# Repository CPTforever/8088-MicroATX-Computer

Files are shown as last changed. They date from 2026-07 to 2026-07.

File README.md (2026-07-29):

# Insert header here

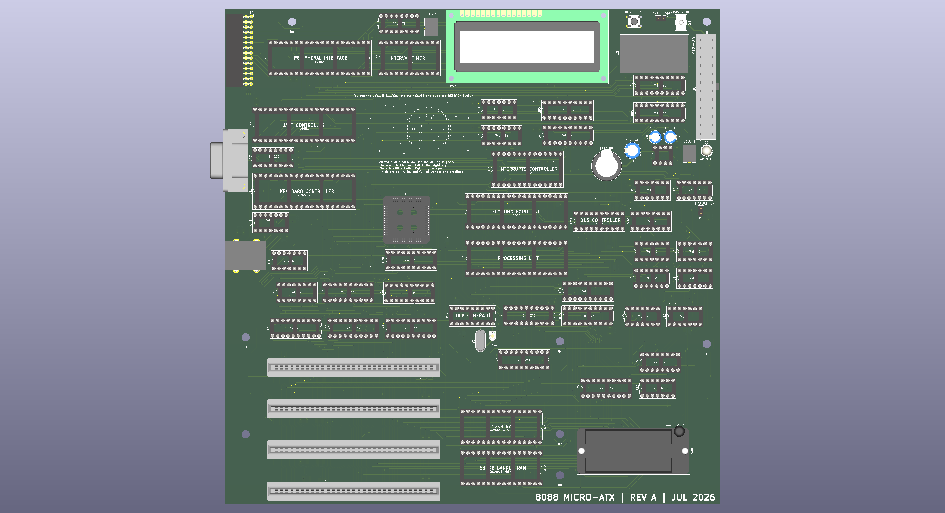
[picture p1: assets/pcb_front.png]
pcb_front

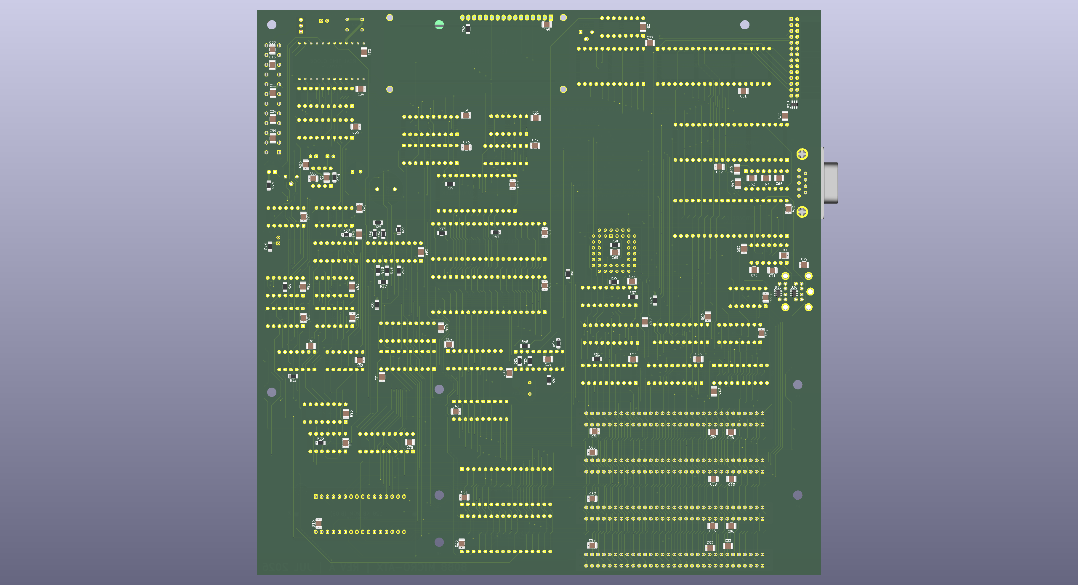
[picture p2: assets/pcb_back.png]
pcb_back

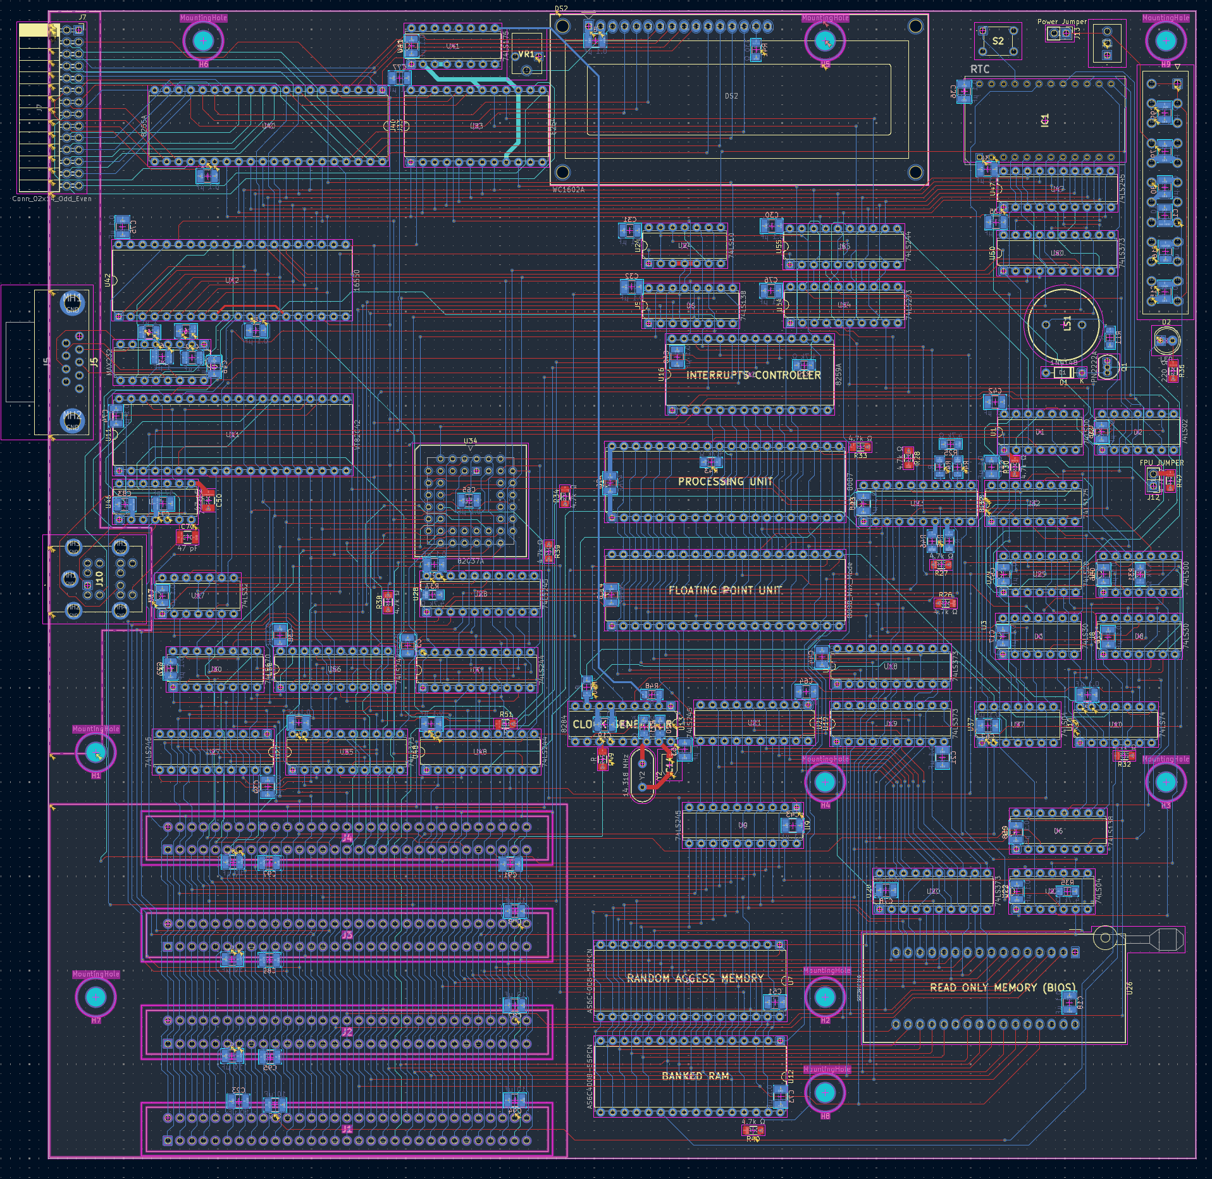
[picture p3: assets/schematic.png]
schematic

# Features!
insert features

# Memory Map
Insert memory map

# I/O Port Map
Insert port map

# Rev 1 Mistakes
UART Controller uses system clock instead of external crystal, meaning standard baud rates are
only achievable when system clock uses a UART compatible crystal

PIT Gate 1 does not have a pull up resistor, meaning gate is floating when the external io pin is not connected. (This can be bodged with a radial resistor at least.)

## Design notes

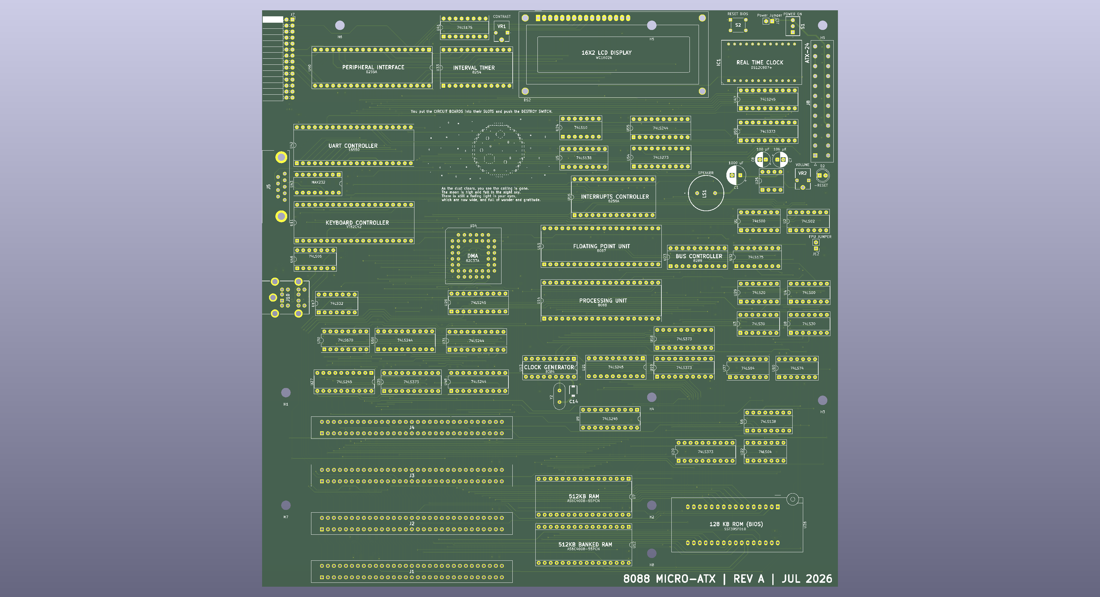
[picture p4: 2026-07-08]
assets/pcb_front_bare.png

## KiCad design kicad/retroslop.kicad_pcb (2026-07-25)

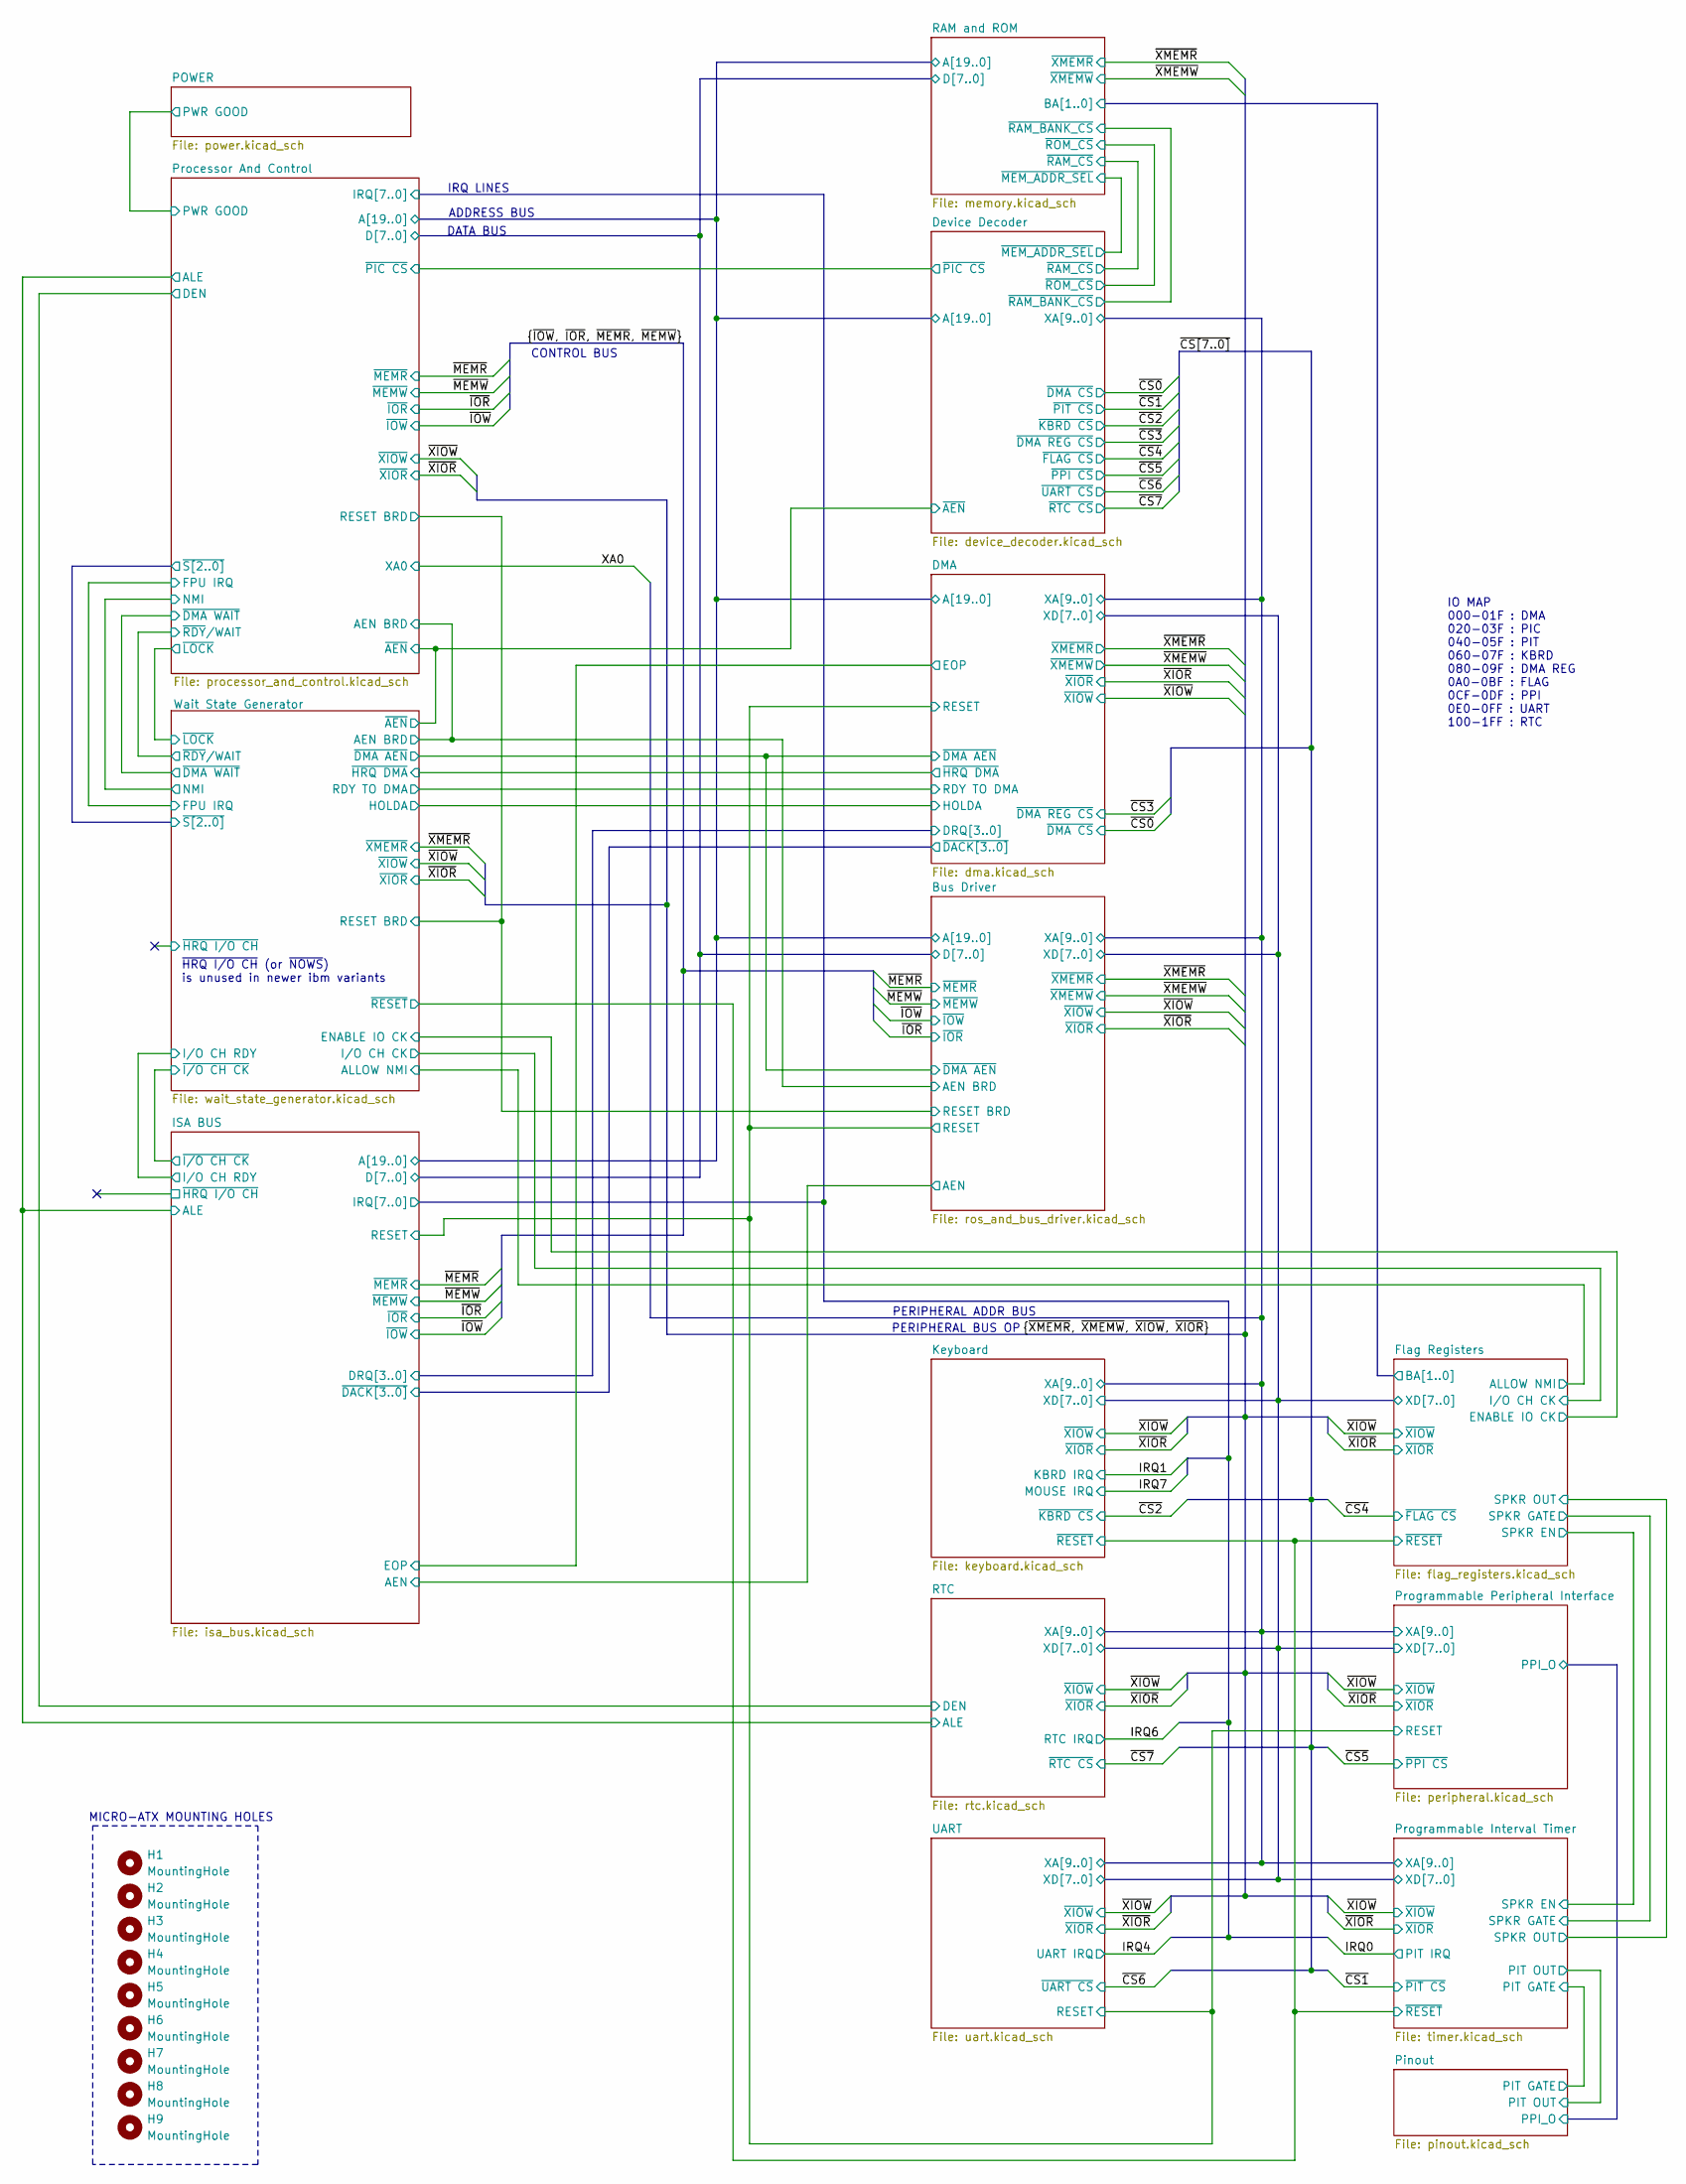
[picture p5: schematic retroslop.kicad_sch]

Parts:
H1, H2, H3, H4, H5, H6, H7, H8, H9: MountingHole; MountingHole_4mm

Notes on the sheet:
DATA BUS
IRQ LINES
IO MAP 000-01F : DMA 020-03F : PIC 040-05F : PIT 060-07F : KBRD 080-09F : DMA REG 0A0-0BF : FLAG 0CF-0DF : PPI 0E0-0FF : UART 100-1FF : RTC
~{HRQ I/O CH} (or ~{NOWS}) is unused in newer ibm variants
ADDRESS BUS
MICRO-ATX MOUNTING HOLES
PERIPHERAL ADDR BUS
CONTROL BUS
PERIPHERAL BUS OP

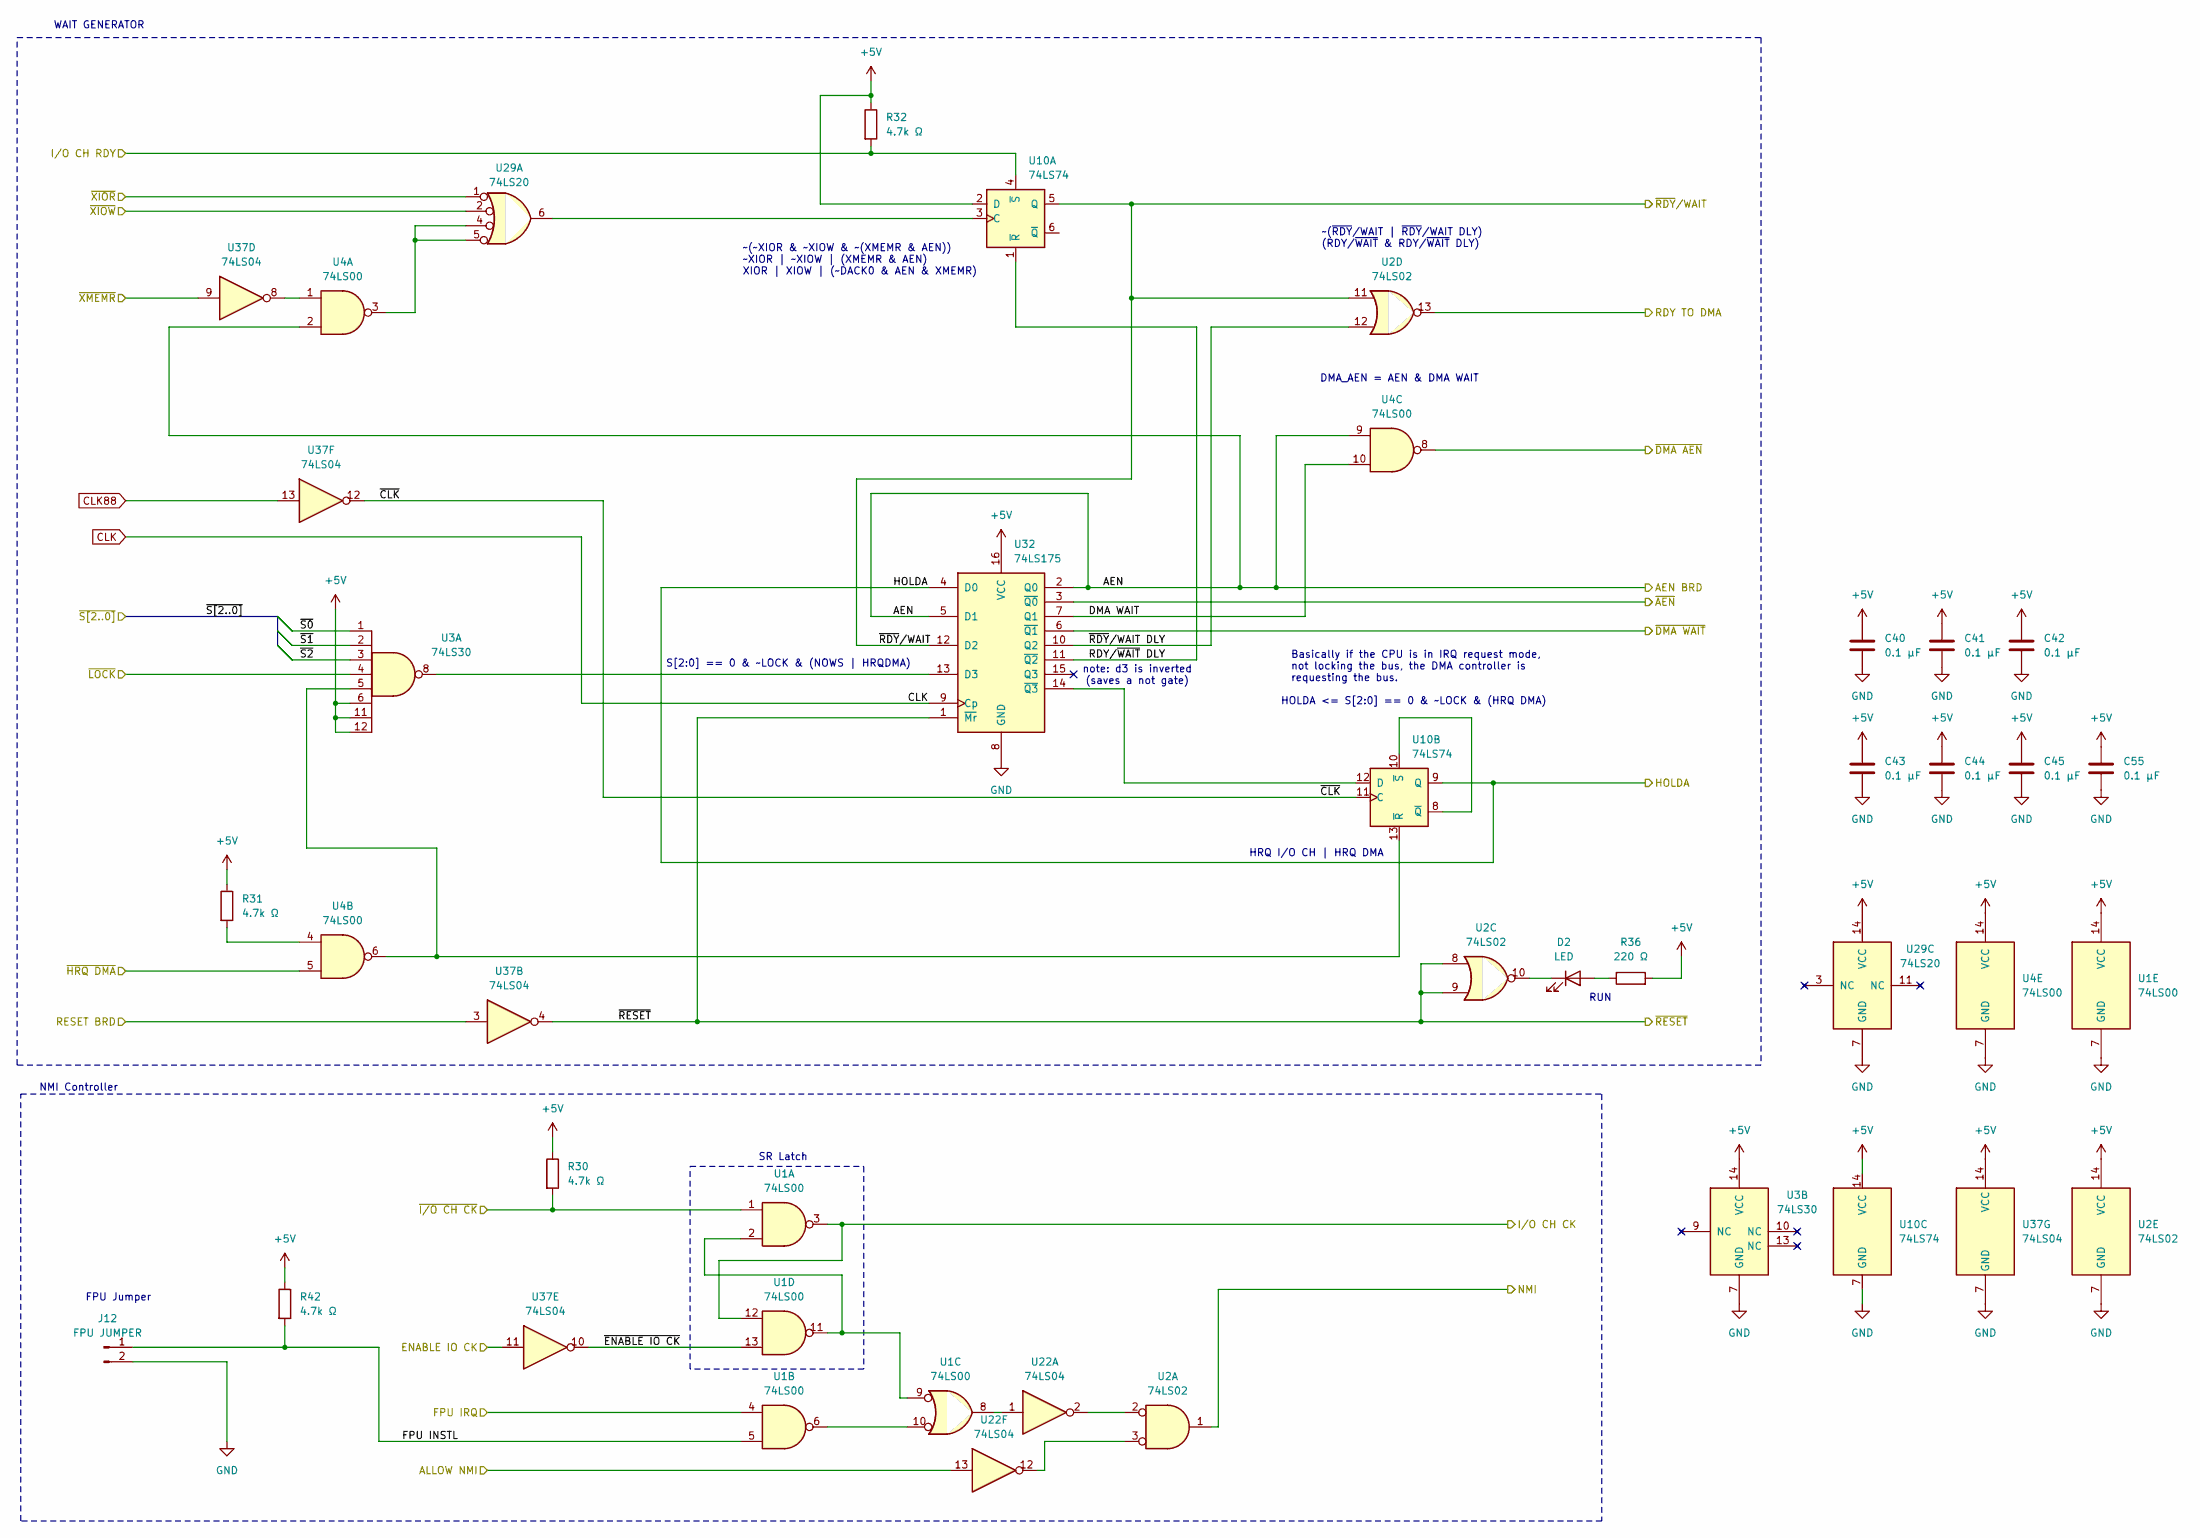
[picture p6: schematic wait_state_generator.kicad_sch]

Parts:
C40, C41, C42, C43, C44, C45, C55: 0.1 μF; C_1210_3225Metric_Pad1.33x2.70mm_HandSolder
D2: LED; LED_D5.0mm_Clear
J12: FPU JUMPER; PinHeader_1x02_P2.54mm_Vertical
R30, R31, R32, R42: 4.7k Ω; R_1206_3216Metric_Pad1.30x1.75mm_HandSolder
R36: 220 Ω; R_1206_3216Metric_Pad1.30x1.75mm_HandSolder
U1, U4: 74LS00; DIP-14_W7.62mm_Socket
U2: 74LS02; DIP-14_W7.62mm_Socket
U3: 74LS30; DIP-14_W7.62mm_Socket
U10: 74LS74; DIP-14_W7.62mm_Socket
U22, U37: 74LS04; DIP-14_W7.62mm_Socket
U29: 74LS20; DIP-14_W7.62mm_Socket
U32: 74LS175; DIP-16_W7.62mm_Socket

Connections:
+5V: C40.1, C41.1, C42.1, C43.1, C44.1, C45.1, C55.1, R30.1, R31.1, R32.1, R36.2, R42.1, U1.14 (VCC), U2.14 (VCC), U3.6, U3.11, U3.12, U3.14 (VCC), U4.14 (VCC), U10.2 (D), U10.14 (VCC), U29.14 (VCC), U32.16 (VCC), U37.14 (VCC); also elsewhere on the board
/Bus Driver/RESET BRD: U37.3; also elsewhere on the board
/Bus Driver/~DMA AEN: U4.8; also elsewhere on the board
/DMA/RDY TO DMA: U2.13; also elsewhere on the board
/DMA/~HRQ DMA: U4.5; also elsewhere on the board
/Device Decoder/~AEN: U32.3 (~Q0); also elsewhere on the board
/Flag Registers/ALLOW NMI: U22.13; also elsewhere on the board
/Flag Registers/ENABLE IO CK: U37.11; also elsewhere on the board
/Flag Registers/I/O CH CK: U1.3, U1.12; also elsewhere on the board
/ISA BUS/I/O CH RDY: R32.2, U10.4 (~S); also elsewhere on the board
/ISA BUS/~I/O CH CK: R30.2, U1.1; also elsewhere on the board
/Processor And Control/FPU IRQ: U1.4; also elsewhere on the board
/Processor And Control/NMI: U2.1; also elsewhere on the board
/Processor And Control/~DMA WAIT: U32.6 (~Q1); also elsewhere on the board
/Processor And Control/~LOCK: U3.4; also elsewhere on the board
/Processor And Control/~S0: U3.1; also elsewhere on the board
/Processor And Control/~S1: U3.2; also elsewhere on the board
/Processor And Control/~S2: U3.3; also elsewhere on the board
/Wait State Generator/AEN: U4.2, U4.9, U32.2 (Q0), U32.5 (D1); also elsewhere on the board
/Wait State Generator/DMA WAIT: U4.10, U32.7 (Q1)
/Wait State Generator/FPU INSTL: J12.1, R42.2, U1.5
/Wait State Generator/HOLDA: U10.9 (Q), U32.4 (D0); also elsewhere on the board
/Wait State Generator/RDY/~WAIT DLY: U10.1 (~R), U32.11 (~Q2)
/Wait State Generator/~CLK: U10.11 (C), U37.12
/Wait State Generator/~ENABLE IO CK: U1.13, U37.10
/Wait State Generator/~RDY/WAIT: U2.11, U10.5 (Q), U32.12 (D2); also elsewhere on the board
/Wait State Generator/~RDY/WAIT DLY: U2.12, U32.10 (Q2)
/Wait State Generator/~RESET: U2.8, U2.9, U32.1 (~Mr), U37.4; also elsewhere on the board
/~XIOR: U29.1; also elsewhere on the board
/~XIOW: U29.2; also elsewhere on the board
/~XMEMR: U37.9; also elsewhere on the board
CLK: U32.9 (Cp); also elsewhere on the board
CLK88: U37.13; also elsewhere on the board
GND: C40.2, C41.2, C42.2, C43.2, C44.2, C45.2, C55.2, J12.2, U1.7 (GND), U2.7 (GND), U3.7 (GND), U4.7 (GND), U10.7 (GND), U29.7 (GND), U32.8 (GND), U37.7 (GND); also elsewhere on the board
unnamed: D2.2 (A), R36.1
unnamed: D2.1 (K), U2.10
unnamed: R31.2, U4.4
unnamed: U1.8, U22.1
unnamed: U1.6, U1.10
unnamed: U1.2, U1.9, U1.11
unnamed: U2.2, U22.2
unnamed: U2.3, U22.12
unnamed: U10.3 (C), U29.6
unnamed: U10.12 (D), U32.14 (~Q3)
unnamed: U10.8 (~Q), U10.10 (~S)
unnamed: U3.5, U4.6, U10.13 (~R)
unnamed: U4.3, U29.4, U29.5
unnamed: U3.8, U32.13 (D3)
unnamed: U4.1, U37.8

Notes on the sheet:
note: d3 is inverted (saves a not gate)
NMI Controller
RUN
~(~XIOR & ~XIOW & ~(XMEMR & AEN)) ~XIOR | ~XIOW | (XMEMR & AEN) XIOR | XIOW | (~DACK0 & AEN & XMEMR)
WAIT GENERATOR
SR Latch
Basically if the CPU is in IRQ request mode, not locking the bus, the DMA controller is requesting the bus.
HRQ I/O CH | HRQ DMA
FPU Jumper
HOLDA <= S[2:0] == 0 & ~LOCK & (HRQ DMA)
S[2:0] == 0 & ~LOCK & (NOWS | HRQDMA)
DMA_AEN = AEN & DMA WAIT
~(~{RDY}/WAIT | ~{RDY}/WAIT DLY) (RDY/~{WAIT} & RDY/~{WAIT} DLY)

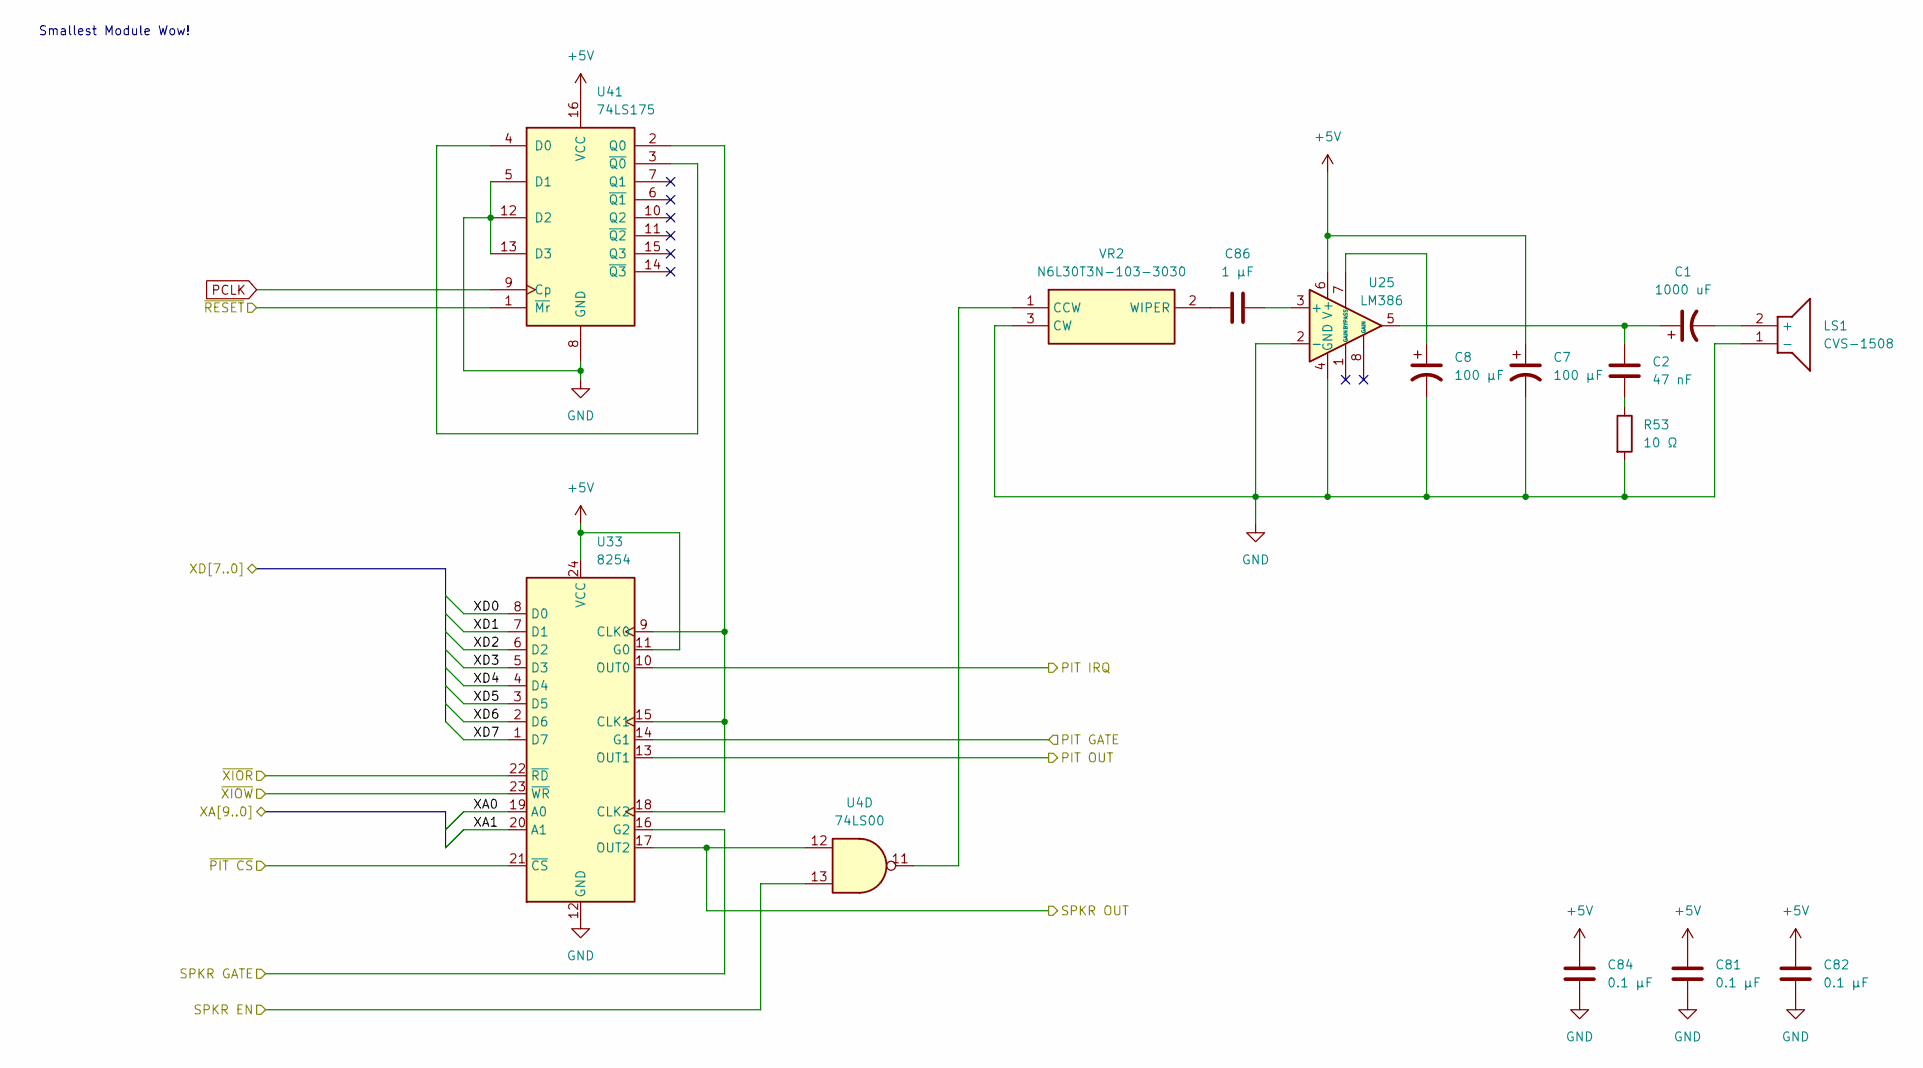
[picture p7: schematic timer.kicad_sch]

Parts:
C1: 1000 uF; CP_Radial_D8.0mm_P3.50mm
C2: 47 nF; C_1210_3225Metric_Pad1.33x2.70mm_HandSolder
C7, C8: 100 μF; CP_Radial_D6.3mm_P2.50mm
C81, C82, C84: 0.1 μF; C_1210_3225Metric_Pad1.33x2.70mm_HandSolder
C86: 1 μF; C_1210_3225Metric_Pad1.33x2.70mm_HandSolder
LS1: CVS-1508; Mouser Part Number 490-CVS-1508
R53: 10 Ω; R_1206_3216Metric_Pad1.30x1.75mm_HandSolder
U4: 74LS00; DIP-14_W7.62mm_Socket
U25: LM386; DIP-8_W7.62mm_Socket
U33: 8254; DIP-24_W15.24mm_Socket
U41: 74LS175; DIP-16_W7.62mm_Socket
VR2: N6L30T3N-103-3030; N6L30T3N1033030; Manufacturer_Part_Number N6L30T3N-103-3030

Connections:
+5V: C7.1, C81.1, C82.1, C84.1, U25.6 (V+), U33.11 (G0), U33.24 (VCC), U41.16 (VCC); also elsewhere on the board
/Bus Driver/XA0: U33.19 (A0); also elsewhere on the board
/Bus Driver/XA1: U33.20 (A1); also elsewhere on the board
/Bus Driver/XD0: U33.8 (D0); also elsewhere on the board
/Bus Driver/XD1: U33.7 (D1); also elsewhere on the board
/Bus Driver/XD2: U33.6 (D2); also elsewhere on the board
/Bus Driver/XD3: U33.5 (D3); also elsewhere on the board
/Bus Driver/XD4: U33.4 (D4); also elsewhere on the board
/Bus Driver/XD5: U33.3 (D5); also elsewhere on the board
/Bus Driver/XD6: U33.2 (D6); also elsewhere on the board
/Bus Driver/XD7: U33.1 (D7); also elsewhere on the board
/Flag Registers/SPKR EN: U4.13; also elsewhere on the board
/Flag Registers/SPKR GATE: U33.16 (G2); also elsewhere on the board
/Flag Registers/SPKR OUT: U4.12, U33.17 (OUT2); also elsewhere on the board
/Pinout/PIT GATE: U33.14 (G1); also elsewhere on the board
/Pinout/PIT OUT: U33.13 (OUT1); also elsewhere on the board
/Processor And Control/IRQ0: U33.10 (OUT0); also elsewhere on the board
/Wait State Generator/~RESET: U41.1 (~Mr); also elsewhere on the board
/~CS1: U33.21 (~CS); also elsewhere on the board
/~XIOR: U33.22 (~RD); also elsewhere on the board
/~XIOW: U33.23 (~WR); also elsewhere on the board
GND: C7.2, C8.2, C81.2, C82.2, C84.2, LS1.1 (-), R53.2, U25.2 (-), U25.4 (GND), U33.12 (GND), U41.5 (D1), U41.8 (GND), U41.12 (D2), U41.13 (D3), VR2.3 (CW); also elsewhere on the board
unnamed: C1.1, C2.1, U25.5
unnamed: C2.2, R53.1
unnamed: C1.2, LS1.2 (+)
unnamed: C86.2, U25.3 (+)
unnamed: C8.1, U25.7 (BYPASS)
unnamed: U33.9 (CLK0), U33.15 (CLK1), U33.18 (CLK2), U41.2 (Q0)
unnamed: U41.3 (~Q0), U41.4 (D0)
unnamed: U4.11, VR2.1 (CCW)
unnamed: C86.1, VR2.2 (WIPER)
PCLK: U41.9 (Cp); also elsewhere on the board

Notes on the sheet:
Smallest Module Wow!

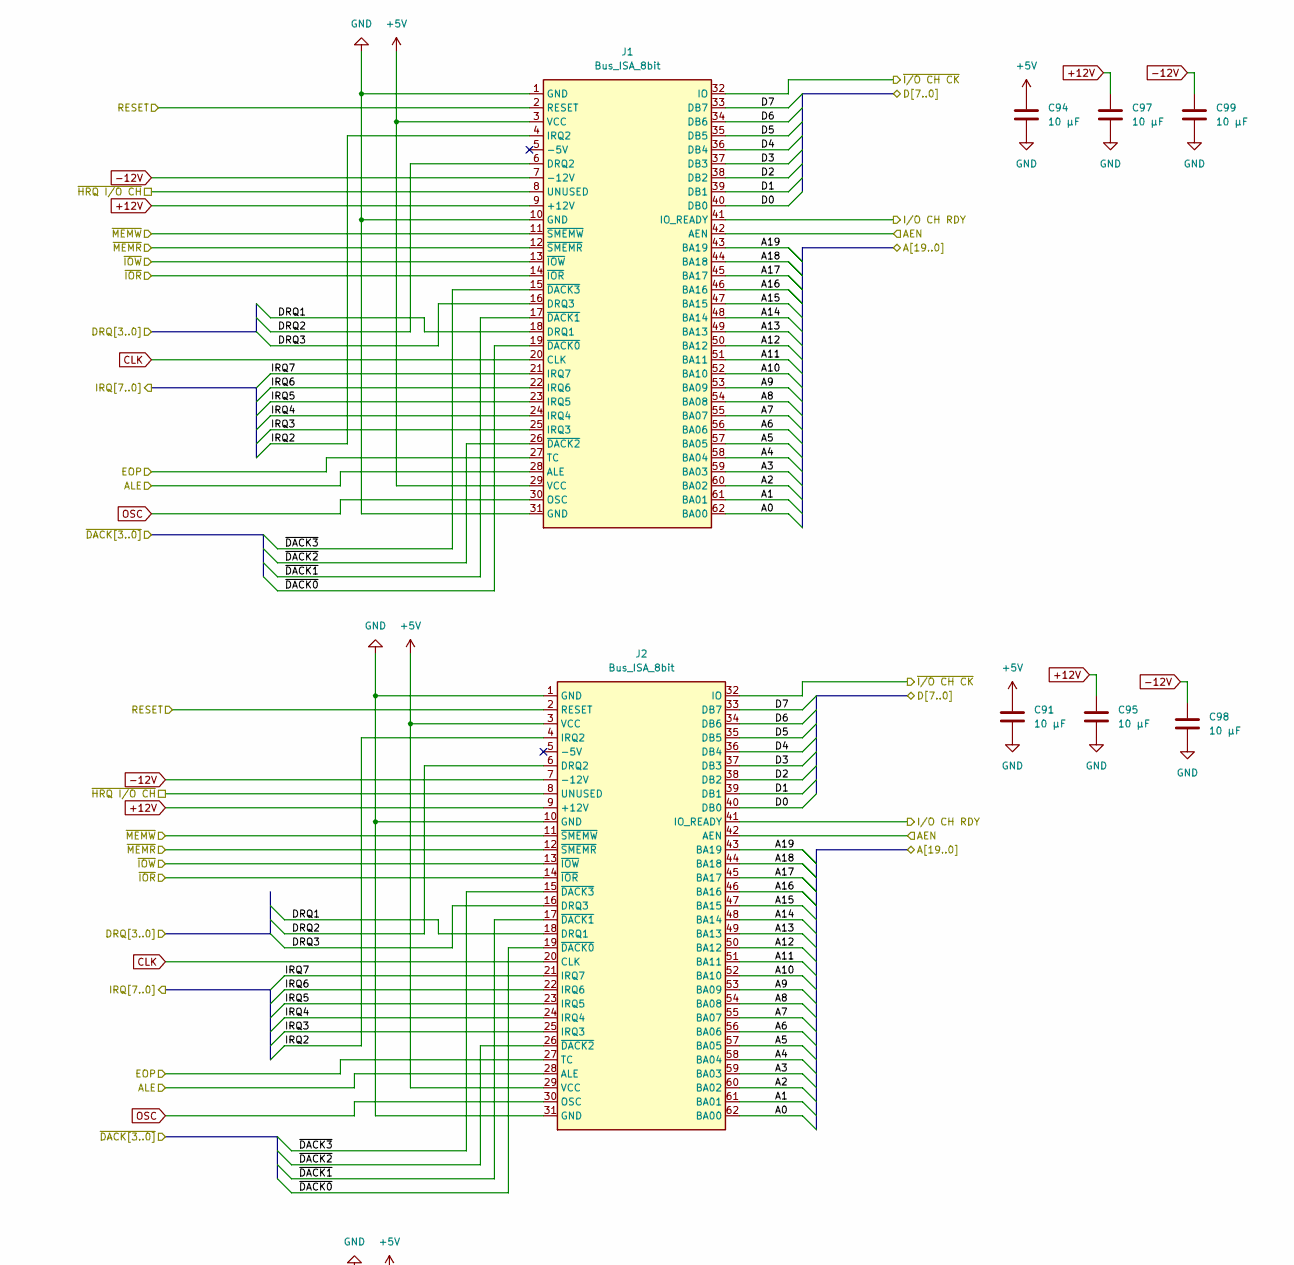
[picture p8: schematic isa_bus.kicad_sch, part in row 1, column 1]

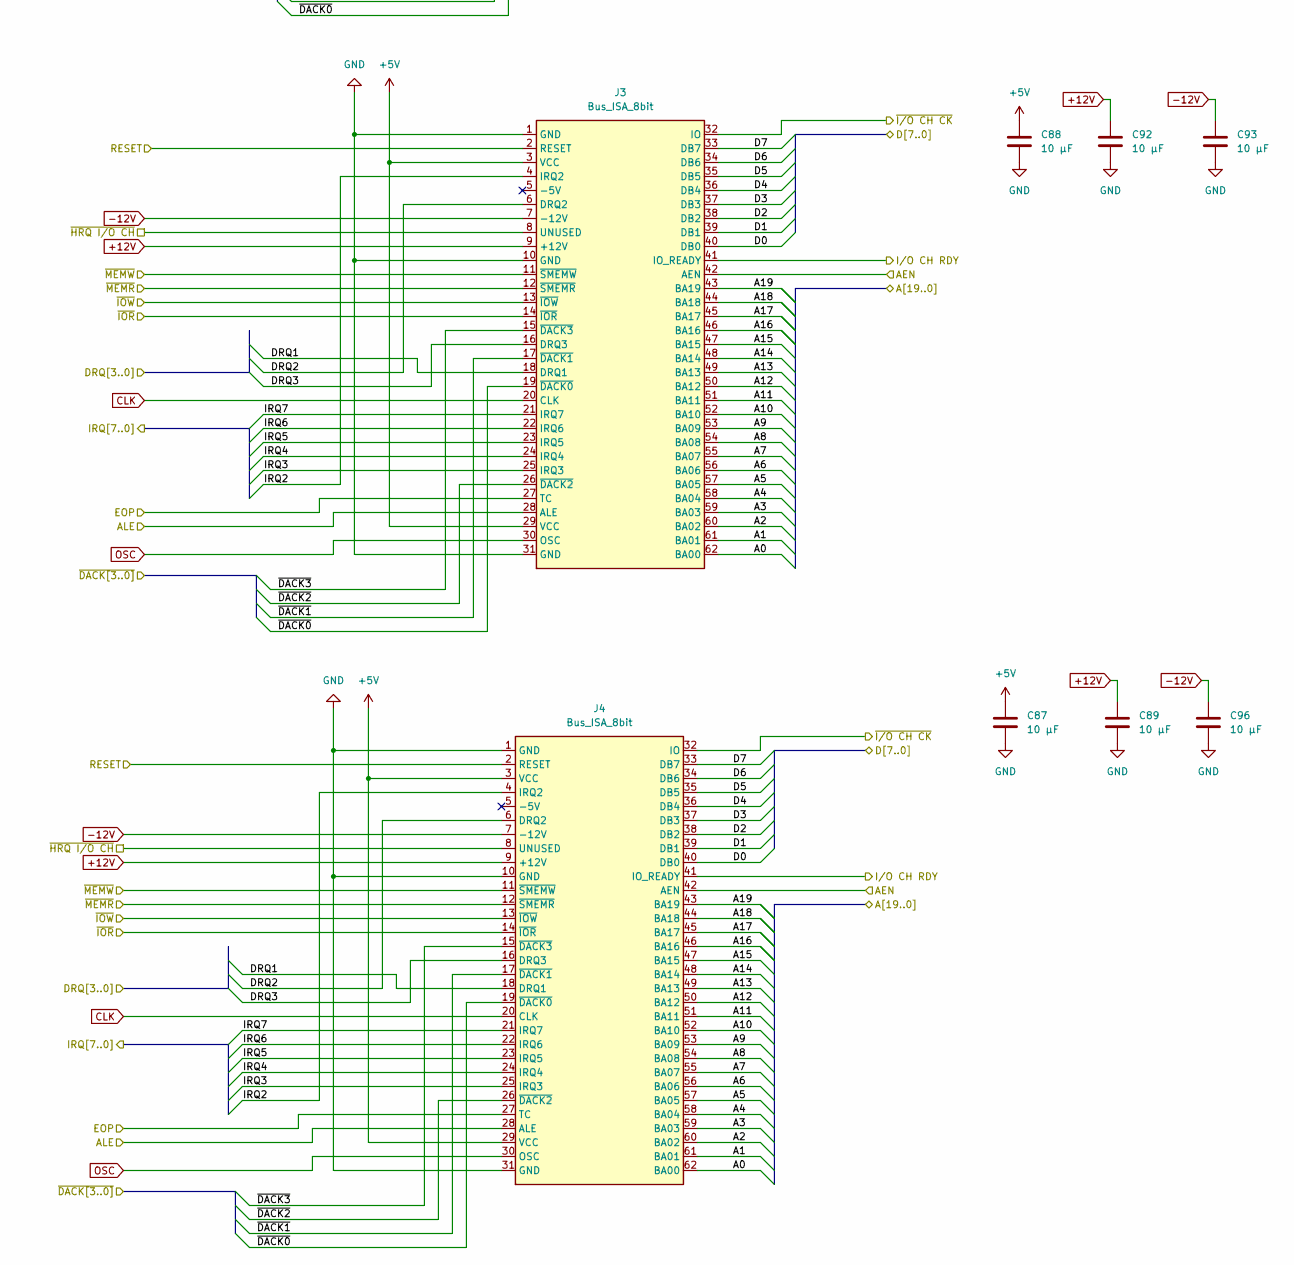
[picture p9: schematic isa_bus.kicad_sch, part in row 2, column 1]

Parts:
C87, C88, C89, C91, C92, C93, C94, C95, C96, C97, C98, C99: 10 μF; C_1210_3225Metric_Pad1.33x2.70mm_HandSolder
J1, J2, J3, J4: Bus_ISA_8bit; 655308435

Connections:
+5V: C87.1, C88.1, C91.1, C94.1, J1.3 (VCC), J1.29 (VCC), J2.3 (VCC), J2.29 (VCC), J3.3 (VCC), J3.29 (VCC), J4.3 (VCC), J4.29 (VCC); also elsewhere on the board
+12V: C89.1, C92.1, C95.1, C97.1, J1.9 (+12V), J2.9 (+12V), J3.9 (+12V), J4.9 (+12V); also elsewhere on the board
-12V: C93.1, C96.1, C98.1, C99.1, J1.7 (-12V), J2.7 (-12V), J3.7 (-12V), J4.7 (-12V); also elsewhere on the board
/Bus Driver/A0: J1.62 (BA00), J2.62 (BA00), J3.62 (BA00), J4.62 (BA00); also elsewhere on the board
/Bus Driver/A1: J1.61 (BA01), J2.61 (BA01), J3.61 (BA01), J4.61 (BA01); also elsewhere on the board
/Bus Driver/A2: J1.60 (BA02), J2.60 (BA02), J3.60 (BA02), J4.60 (BA02); also elsewhere on the board
/Bus Driver/A3: J1.59 (BA03), J2.59 (BA03), J3.59 (BA03), J4.59 (BA03); also elsewhere on the board
/Bus Driver/A4: J1.58 (BA04), J2.58 (BA04), J3.58 (BA04), J4.58 (BA04); also elsewhere on the board
/Bus Driver/A5: J1.57 (BA05), J2.57 (BA05), J3.57 (BA05), J4.57 (BA05); also elsewhere on the board
/Bus Driver/A6: J1.56 (BA06), J2.56 (BA06), J3.56 (BA06), J4.56 (BA06); also elsewhere on the board
/Bus Driver/A7: J1.55 (BA07), J2.55 (BA07), J3.55 (BA07), J4.55 (BA07); also elsewhere on the board
/Bus Driver/A8: J1.54 (BA08), J2.54 (BA08), J3.54 (BA08), J4.54 (BA08); also elsewhere on the board
/Bus Driver/A9: J1.53 (BA09), J2.53 (BA09), J3.53 (BA09), J4.53 (BA09); also elsewhere on the board
/Bus Driver/A10: J1.52 (BA10), J2.52 (BA10), J3.52 (BA10), J4.52 (BA10); also elsewhere on the board
/Bus Driver/A11: J1.51 (BA11), J2.51 (BA11), J3.51 (BA11), J4.51 (BA11); also elsewhere on the board
/Bus Driver/A12: J1.50 (BA12), J2.50 (BA12), J3.50 (BA12), J4.50 (BA12); also elsewhere on the board
/Bus Driver/A13: J1.49 (BA13), J2.49 (BA13), J3.49 (BA13), J4.49 (BA13); also elsewhere on the board
/Bus Driver/A14: J1.48 (BA14), J2.48 (BA14), J3.48 (BA14), J4.48 (BA14); also elsewhere on the board
/Bus Driver/A15: J1.47 (BA15), J2.47 (BA15), J3.47 (BA15), J4.47 (BA15); also elsewhere on the board
/Bus Driver/A16: J1.46 (BA16), J2.46 (BA16), J3.46 (BA16), J4.46 (BA16); also elsewhere on the board
/Bus Driver/A17: J1.45 (BA17), J2.45 (BA17), J3.45 (BA17), J4.45 (BA17); also elsewhere on the board
/Bus Driver/A18: J1.44 (BA18), J2.44 (BA18), J3.44 (BA18), J4.44 (BA18); also elsewhere on the board
/Bus Driver/A19: J1.43 (BA19), J2.43 (BA19), J3.43 (BA19), J4.43 (BA19); also elsewhere on the board
/Bus Driver/AEN: J1.42 (AEN), J2.42 (AEN), J3.42 (AEN), J4.42 (AEN); also elsewhere on the board
/Bus Driver/D0: J1.40 (DB0), J2.40 (DB0), J3.40 (DB0), J4.40 (DB0); also elsewhere on the board
/Bus Driver/D1: J1.39 (DB1), J2.39 (DB1), J3.39 (DB1), J4.39 (DB1); also elsewhere on the board
/Bus Driver/D2: J1.38 (DB2), J2.38 (DB2), J3.38 (DB2), J4.38 (DB2); also elsewhere on the board
/Bus Driver/D3: J1.37 (DB3), J2.37 (DB3), J3.37 (DB3), J4.37 (DB3); also elsewhere on the board
/Bus Driver/D4: J1.36 (DB4), J2.36 (DB4), J3.36 (DB4), J4.36 (DB4); also elsewhere on the board
/Bus Driver/D5: J1.35 (DB5), J2.35 (DB5), J3.35 (DB5), J4.35 (DB5); also elsewhere on the board
/Bus Driver/D6: J1.34 (DB6), J2.34 (DB6), J3.34 (DB6), J4.34 (DB6); also elsewhere on the board
/Bus Driver/D7: J1.33 (DB7), J2.33 (DB7), J3.33 (DB7), J4.33 (DB7); also elsewhere on the board
/Bus Driver/RESET: J1.2 (RESET), J2.2 (RESET), J3.2 (RESET), J4.2 (RESET); also elsewhere on the board
/DMA/DRQ1: J1.18 (DRQ1), J2.18 (DRQ1), J3.18 (DRQ1), J4.18 (DRQ1); also elsewhere on the board
/DMA/DRQ2: J1.6 (DRQ2), J2.6 (DRQ2), J3.6 (DRQ2), J4.6 (DRQ2); also elsewhere on the board
/DMA/DRQ3: J1.16 (DRQ3), J2.16 (DRQ3), J3.16 (DRQ3), J4.16 (DRQ3); also elsewhere on the board
/DMA/Terminal Count: J1.27 (TC), J2.27 (TC), J3.27 (TC), J4.27 (TC); also elsewhere on the board
/DMA/~DACK0: J1.19 (~DACK0), J2.19 (~DACK0), J3.19 (~DACK0), J4.19 (~DACK0); also elsewhere on the board
/DMA/~DACK1: J1.17 (~DACK1), J2.17 (~DACK1), J3.17 (~DACK1), J4.17 (~DACK1); also elsewhere on the board
/DMA/~DACK2: J1.26 (~DACK2), J2.26 (~DACK2), J3.26 (~DACK2), J4.26 (~DACK2); also elsewhere on the board
/DMA/~DACK3: J1.15 (~DACK3), J2.15 (~DACK3), J3.15 (~DACK3), J4.15 (~DACK3); also elsewhere on the board
/ISA BUS/I/O CH RDY: J1.41 (IO_READY), J2.41 (IO_READY), J3.41 (IO_READY), J4.41 (IO_READY); also elsewhere on the board
/ISA BUS/~HRQ I/O CH: J1.8 (UNUSED), J2.8 (UNUSED), J3.8 (UNUSED), J4.8 (UNUSED)
/ISA BUS/~I/O CH CK: J1.32 (IO), J2.32 (IO), J3.32 (IO), J4.32 (IO); also elsewhere on the board
/Processor And Control/IRQ2: J1.4 (IRQ2), J2.4 (IRQ2), J3.4 (IRQ2), J4.4 (IRQ2); also elsewhere on the board
/Processor And Control/IRQ3: J1.25 (IRQ3), J2.25 (IRQ3), J3.25 (IRQ3), J4.25 (IRQ3); also elsewhere on the board
/Processor And Control/IRQ4: J1.24 (IRQ4), J2.24 (IRQ4), J3.24 (IRQ4), J4.24 (IRQ4); also elsewhere on the board
/Processor And Control/IRQ5: J1.23 (IRQ5), J2.23 (IRQ5), J3.23 (IRQ5), J4.23 (IRQ5); also elsewhere on the board
/Processor And Control/IRQ6: J1.22 (IRQ6), J2.22 (IRQ6), J3.22 (IRQ6), J4.22 (IRQ6); also elsewhere on the board
/Processor And Control/IRQ7: J1.21 (IRQ7), J2.21 (IRQ7), J3.21 (IRQ7), J4.21 (IRQ7); also elsewhere on the board
/RTC/ADDR LATCH: J1.28 (ALE), J2.28 (ALE), J3.28 (ALE), J4.28 (ALE); also elsewhere on the board
/~IOR: J1.14 (~IOR), J2.14 (~IOR), J3.14 (~IOR), J4.14 (~IOR); also elsewhere on the board
/~IOW: J1.13 (~IOW), J2.13 (~IOW), J3.13 (~IOW), J4.13 (~IOW); also elsewhere on the board
/~MEMR: J1.12 (~SMEMR), J2.12 (~SMEMR), J3.12 (~SMEMR), J4.12 (~SMEMR); also elsewhere on the board
/~MEMW: J1.11 (~SMEMW), J2.11 (~SMEMW), J3.11 (~SMEMW), J4.11 (~SMEMW); also elsewhere on the board
CLK: J1.20 (CLK), J2.20 (CLK), J3.20 (CLK), J4.20 (CLK); also elsewhere on the board
GND: C87.2, C88.2, C89.2, C91.2, C92.2, C93.2, C94.2, C95.2, C96.2, C97.2, C98.2, C99.2, J1.1 (GND), J1.10 (GND), J1.31 (GND), J2.1 (GND), J2.10 (GND), J2.31 (GND), J3.1 (GND), J3.10 (GND), J3.31 (GND), J4.1 (GND), J4.10 (GND), J4.31 (GND); also elsewhere on the board
OSC: J1.30 (OSC), J2.30 (OSC), J3.30 (OSC), J4.30 (OSC); also elsewhere on the board

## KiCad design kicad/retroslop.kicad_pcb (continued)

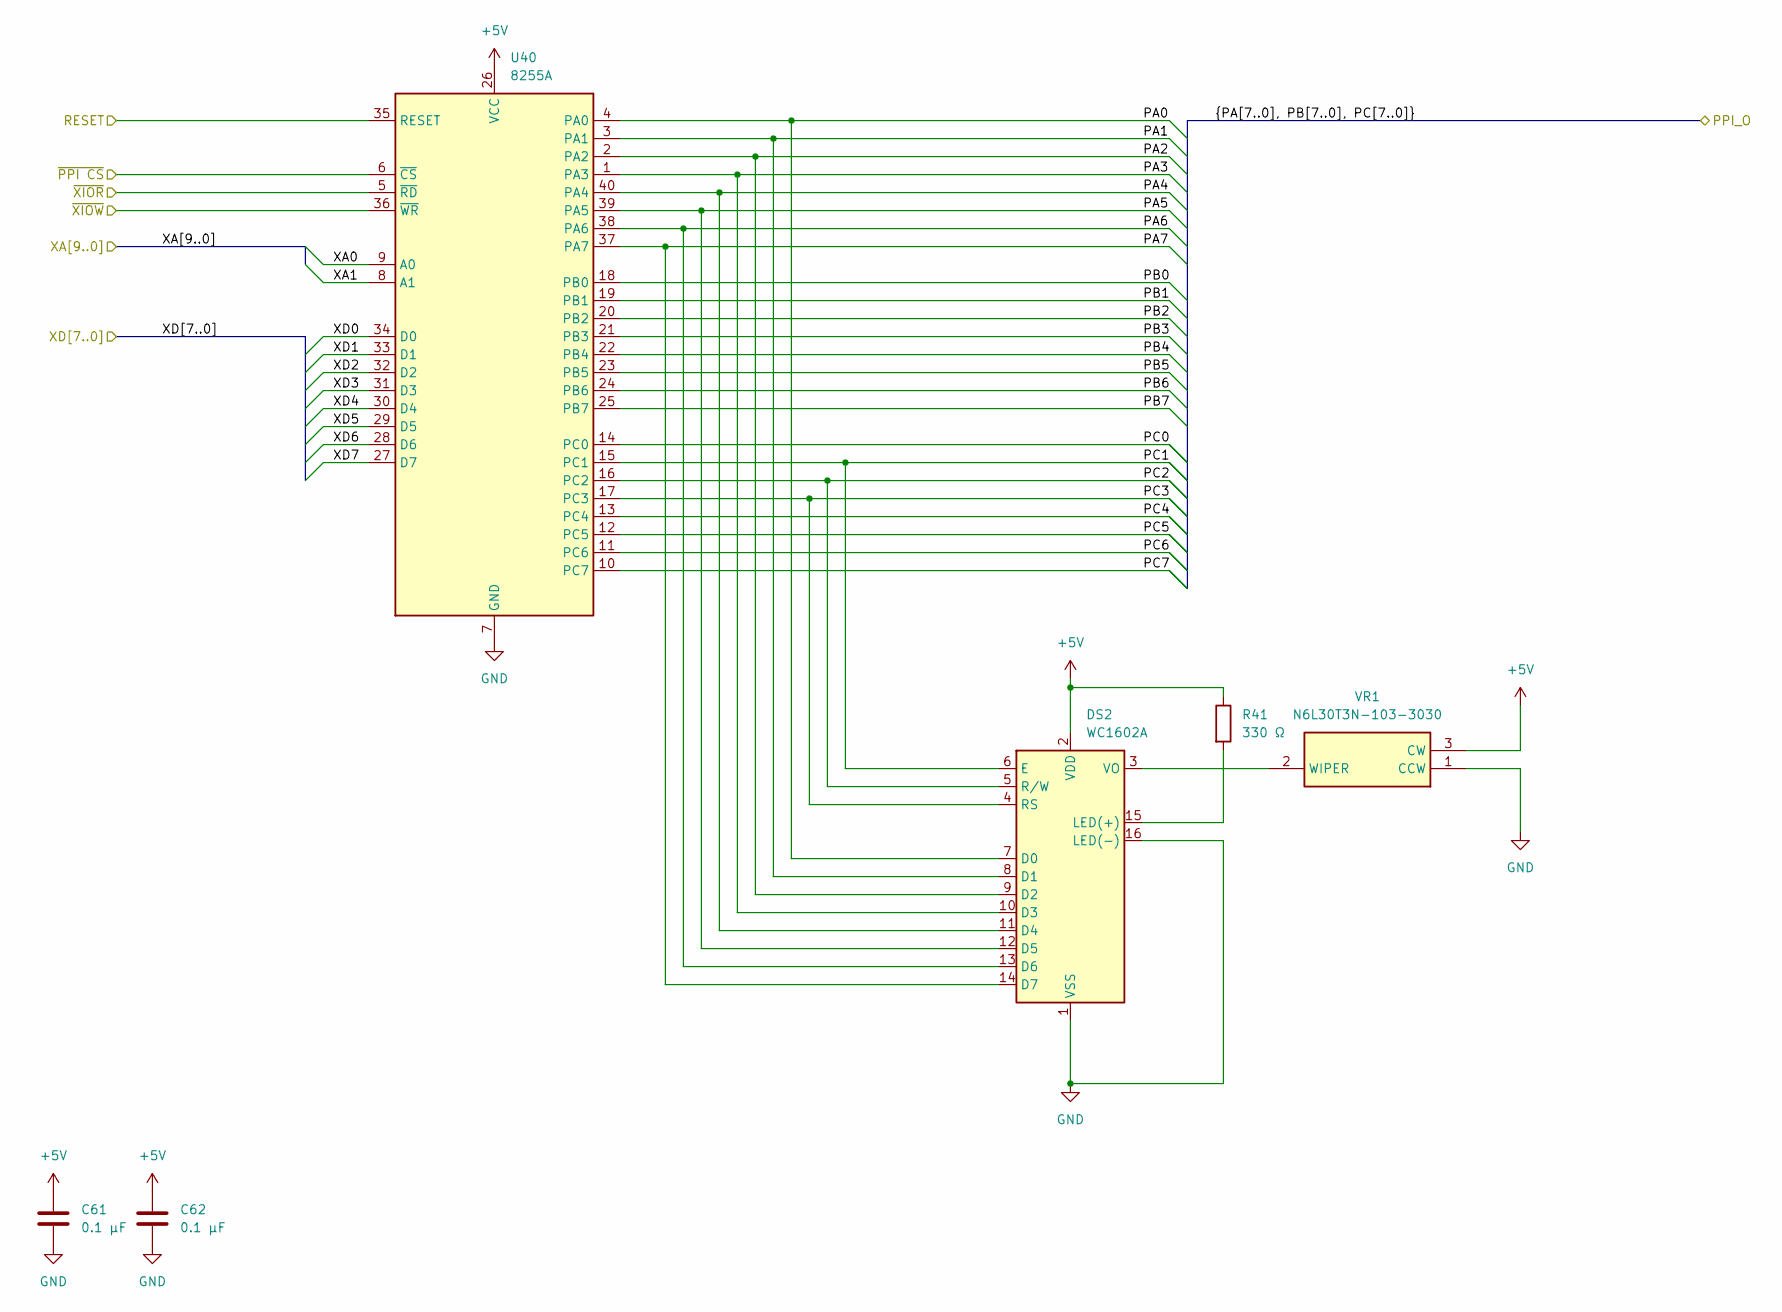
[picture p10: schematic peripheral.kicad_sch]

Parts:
C61, C62: 0.1 μF; C_1210_3225Metric_Pad1.33x2.70mm_HandSolder
DS2: WC1602A
R41: 330 Ω; R_1206_3216Metric_Pad1.30x1.75mm_HandSolder
U40: 8255A; DIP-40_W15.24mm_Socket
VR1: N6L30T3N-103-3030; N6L30T3N1033030; Manufacturer_Part_Number N6L30T3N-103-3030

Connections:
+5V: C61.1, C62.1, DS2.2 (VDD), R41.1, U40.26 (VCC), VR1.3 (CW); also elsewhere on the board
/Bus Driver/RESET: U40.35 (RESET); also elsewhere on the board
/Bus Driver/XA0: U40.9 (A0); also elsewhere on the board
/Bus Driver/XA1: U40.8 (A1); also elsewhere on the board
/Bus Driver/XD0: U40.34 (D0); also elsewhere on the board
/Bus Driver/XD1: U40.33 (D1); also elsewhere on the board
/Bus Driver/XD2: U40.32 (D2); also elsewhere on the board
/Bus Driver/XD3: U40.31 (D3); also elsewhere on the board
/Bus Driver/XD4: U40.30 (D4); also elsewhere on the board
/Bus Driver/XD5: U40.29 (D5); also elsewhere on the board
/Bus Driver/XD6: U40.28 (D6); also elsewhere on the board
/Bus Driver/XD7: U40.27 (D7); also elsewhere on the board
/Pinout/PA0: DS2.7 (D0), U40.4 (PA0); also elsewhere on the board
/Pinout/PA1: DS2.8 (D1), U40.3 (PA1); also elsewhere on the board
/Pinout/PA2: DS2.9 (D2), U40.2 (PA2); also elsewhere on the board
/Pinout/PA3: DS2.10 (D3), U40.1 (PA3); also elsewhere on the board
/Pinout/PA4: DS2.11 (D4), U40.40 (PA4); also elsewhere on the board
/Pinout/PA5: DS2.12 (D5), U40.39 (PA5); also elsewhere on the board
/Pinout/PA6: DS2.13 (D6), U40.38 (PA6); also elsewhere on the board
/Pinout/PA7: DS2.14 (D7), U40.37 (PA7); also elsewhere on the board
/Pinout/PB0: U40.18 (PB0); also elsewhere on the board
/Pinout/PB1: U40.19 (PB1); also elsewhere on the board
/Pinout/PB2: U40.20 (PB2); also elsewhere on the board
/Pinout/PB3: U40.21 (PB3); also elsewhere on the board
/Pinout/PB4: U40.22 (PB4); also elsewhere on the board
/Pinout/PB5: U40.23 (PB5); also elsewhere on the board
/Pinout/PB6: U40.24 (PB6); also elsewhere on the board
/Pinout/PB7: U40.25 (PB7); also elsewhere on the board
/Pinout/PC0: U40.14 (PC0); also elsewhere on the board
/Pinout/PC1: DS2.6 (E), U40.15 (PC1); also elsewhere on the board
/Pinout/PC2: DS2.5 (R/W), U40.16 (PC2); also elsewhere on the board
/Pinout/PC3: DS2.4 (RS), U40.17 (PC3); also elsewhere on the board
/Pinout/PC4: U40.13 (PC4); also elsewhere on the board
/Pinout/PC5: U40.12 (PC5); also elsewhere on the board
/Pinout/PC6: U40.11 (PC6); also elsewhere on the board
/Pinout/PC7: U40.10 (PC7); also elsewhere on the board
/~CS5: U40.6 (~CS); also elsewhere on the board
/~XIOR: U40.5 (~RD); also elsewhere on the board
/~XIOW: U40.36 (~WR); also elsewhere on the board
GND: C61.2, C62.2, DS2.1 (VSS), DS2.16 (LED(-)), U40.7 (GND), VR1.1 (CCW); also elsewhere on the board
unnamed: DS2.15 (LED(+)), R41.2
unnamed: DS2.3 (VO), VR1.2 (WIPER)

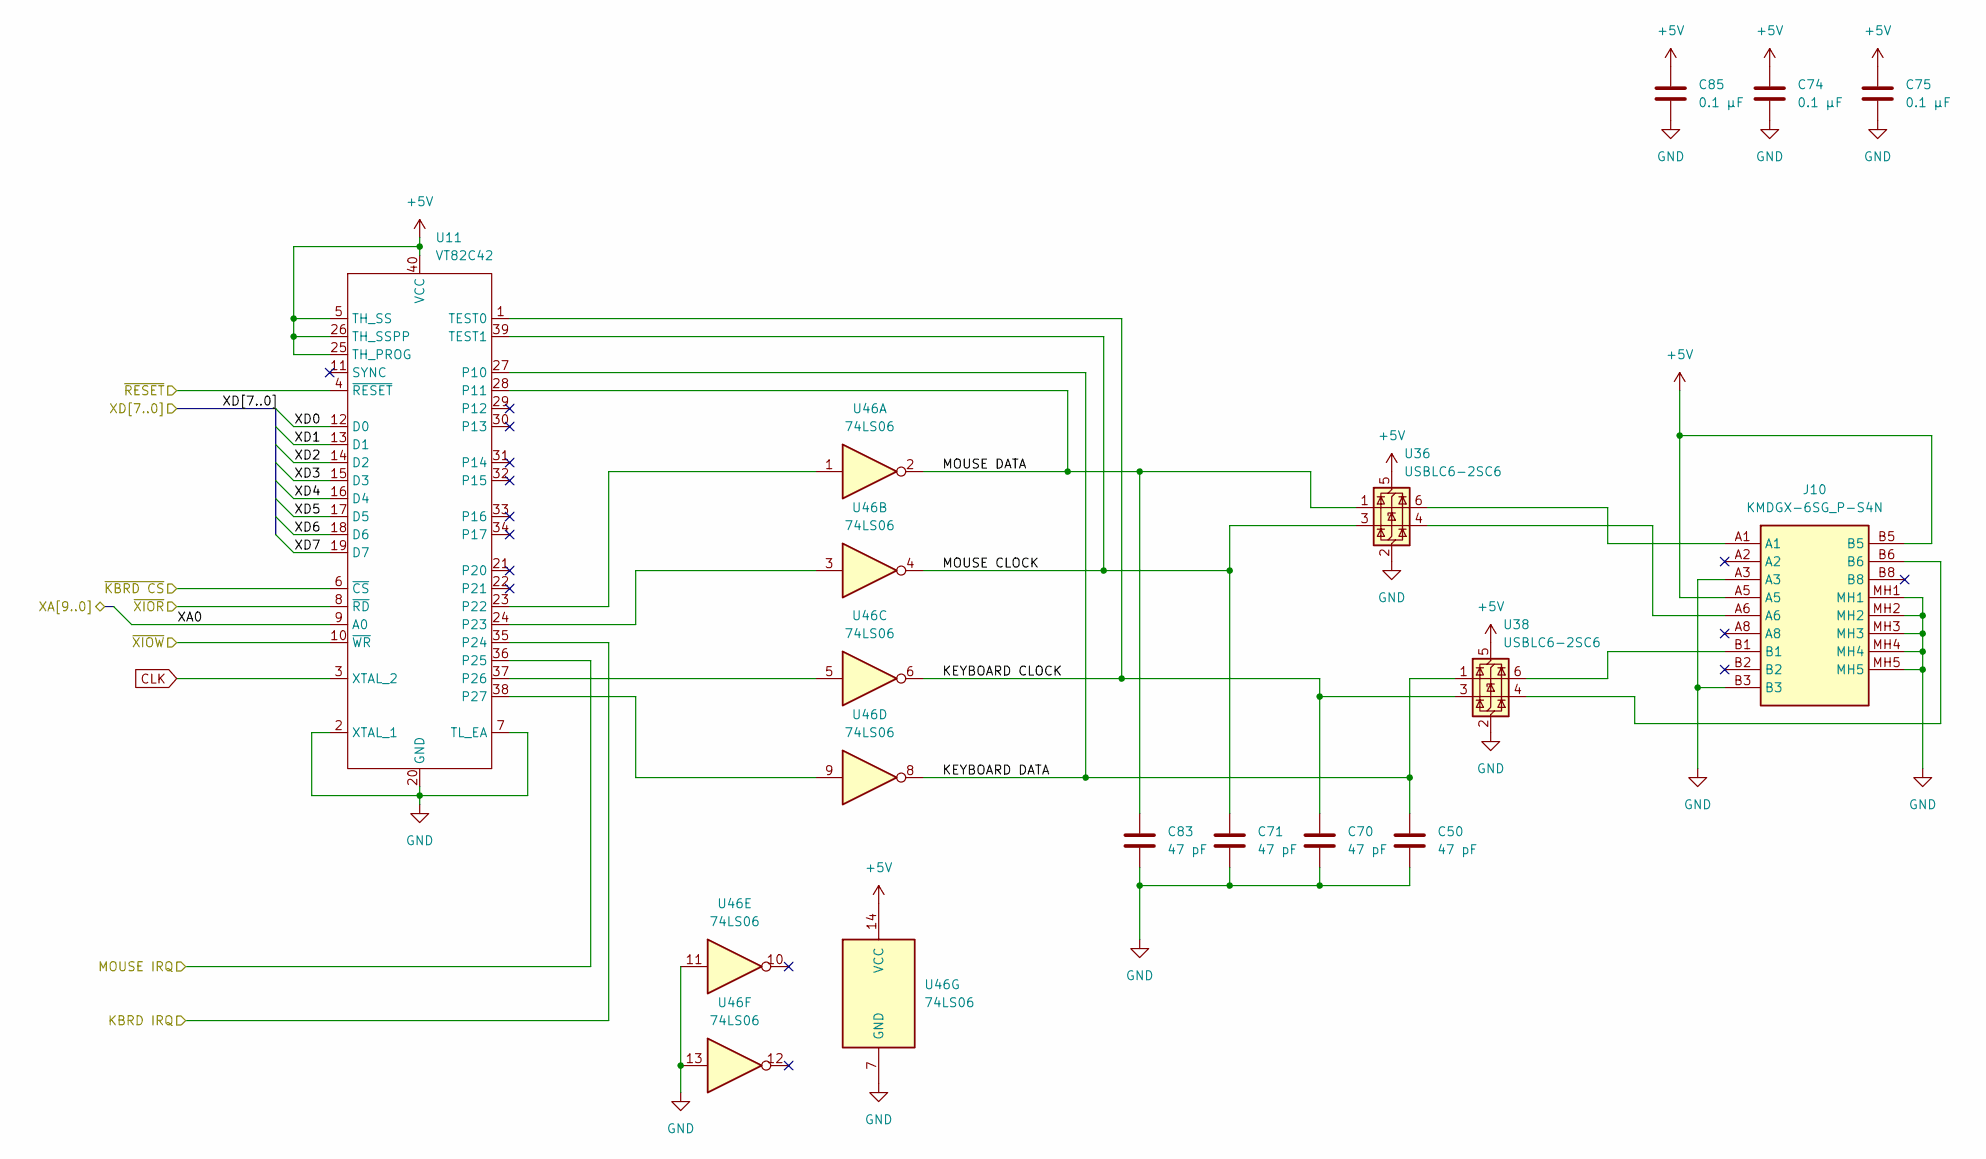
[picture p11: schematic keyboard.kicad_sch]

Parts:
C50, C70, C71, C83: 47 pF; C_1210_3225Metric_Pad1.33x2.70mm_HandSolder
C74, C75, C85: 0.1 μF; C_1210_3225Metric_Pad1.33x2.70mm_HandSolder
J10: KMDGX-6SG_P-S4N; KMDGX6SGPS4N; Mouser Part Number 806-KMDGX-6SGP-S4N
U11: VT82C42; DIP-40_W15.24mm_Socket
U36, U38: USBLC6-2SC6; SOT-23-6
U46: 74LS06; DIP-14_W7.62mm_Socket

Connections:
+5V: C74.1, C75.1, C85.1, J10.A5, J10.B5, U11.5 (TH_SS), U11.25 (TH_PROG), U11.26 (TH_SSPP), U11.40 (VCC), U36.5 (VBUS), U38.5 (VBUS), U46.14 (VCC); also elsewhere on the board
/Bus Driver/XA0: U11.9 (A0); also elsewhere on the board
/Bus Driver/XD0: U11.12 (D0); also elsewhere on the board
/Bus Driver/XD1: U11.13 (D1); also elsewhere on the board
/Bus Driver/XD2: U11.14 (D2); also elsewhere on the board
/Bus Driver/XD3: U11.15 (D3); also elsewhere on the board
/Bus Driver/XD4: U11.16 (D4); also elsewhere on the board
/Bus Driver/XD5: U11.17 (D5); also elsewhere on the board
/Bus Driver/XD6: U11.18 (D6); also elsewhere on the board
/Bus Driver/XD7: U11.19 (D7); also elsewhere on the board
/Keyboard/KEYBOARD CLOCK: C70.1, U11.1 (TEST0), U38.3 (I/O2), U46.6
/Keyboard/KEYBOARD DATA: C50.1, U11.27 (P10), U38.1 (I/O1), U46.8
/Keyboard/MOUSE CLOCK: C71.1, U11.39 (TEST1), U36.3 (I/O2), U46.4
/Keyboard/MOUSE DATA: C83.1, U11.28 (P11), U36.1 (I/O1), U46.2
/Processor And Control/IRQ1: U11.35 (P24); also elsewhere on the board
/Processor And Control/IRQ7: U11.36 (P25); also elsewhere on the board
/Wait State Generator/~RESET: U11.4 (~RESET); also elsewhere on the board
/~CS2: U11.6 (~CS); also elsewhere on the board
/~XIOR: U11.8 (~RD); also elsewhere on the board
/~XIOW: U11.10 (~WR); also elsewhere on the board
CLK: U11.3 (XTAL_2); also elsewhere on the board
GND: C50.2, C70.2, C71.2, C74.2, C75.2, C83.2, C85.2, J10.A3, J10.B3, J10.MH1, J10.MH2, J10.MH3, J10.MH4, J10.MH5, U11.2 (XTAL_1), U11.7 (TL_EA), U11.20 (GND), U36.2 (GND), U38.2 (GND), U46.7 (GND), U46.11, U46.13; also elsewhere on the board
unnamed: J10.A1, U36.6 (I/O1)
unnamed: J10.A6, U36.4 (I/O2)
unnamed: J10.B1, U38.6 (I/O1)
unnamed: J10.B6, U38.4 (I/O2)
unnamed: U11.23 (P22), U46.1
unnamed: U11.24 (P23), U46.3
unnamed: U11.37 (P26), U46.5
unnamed: U11.38 (P27), U46.9

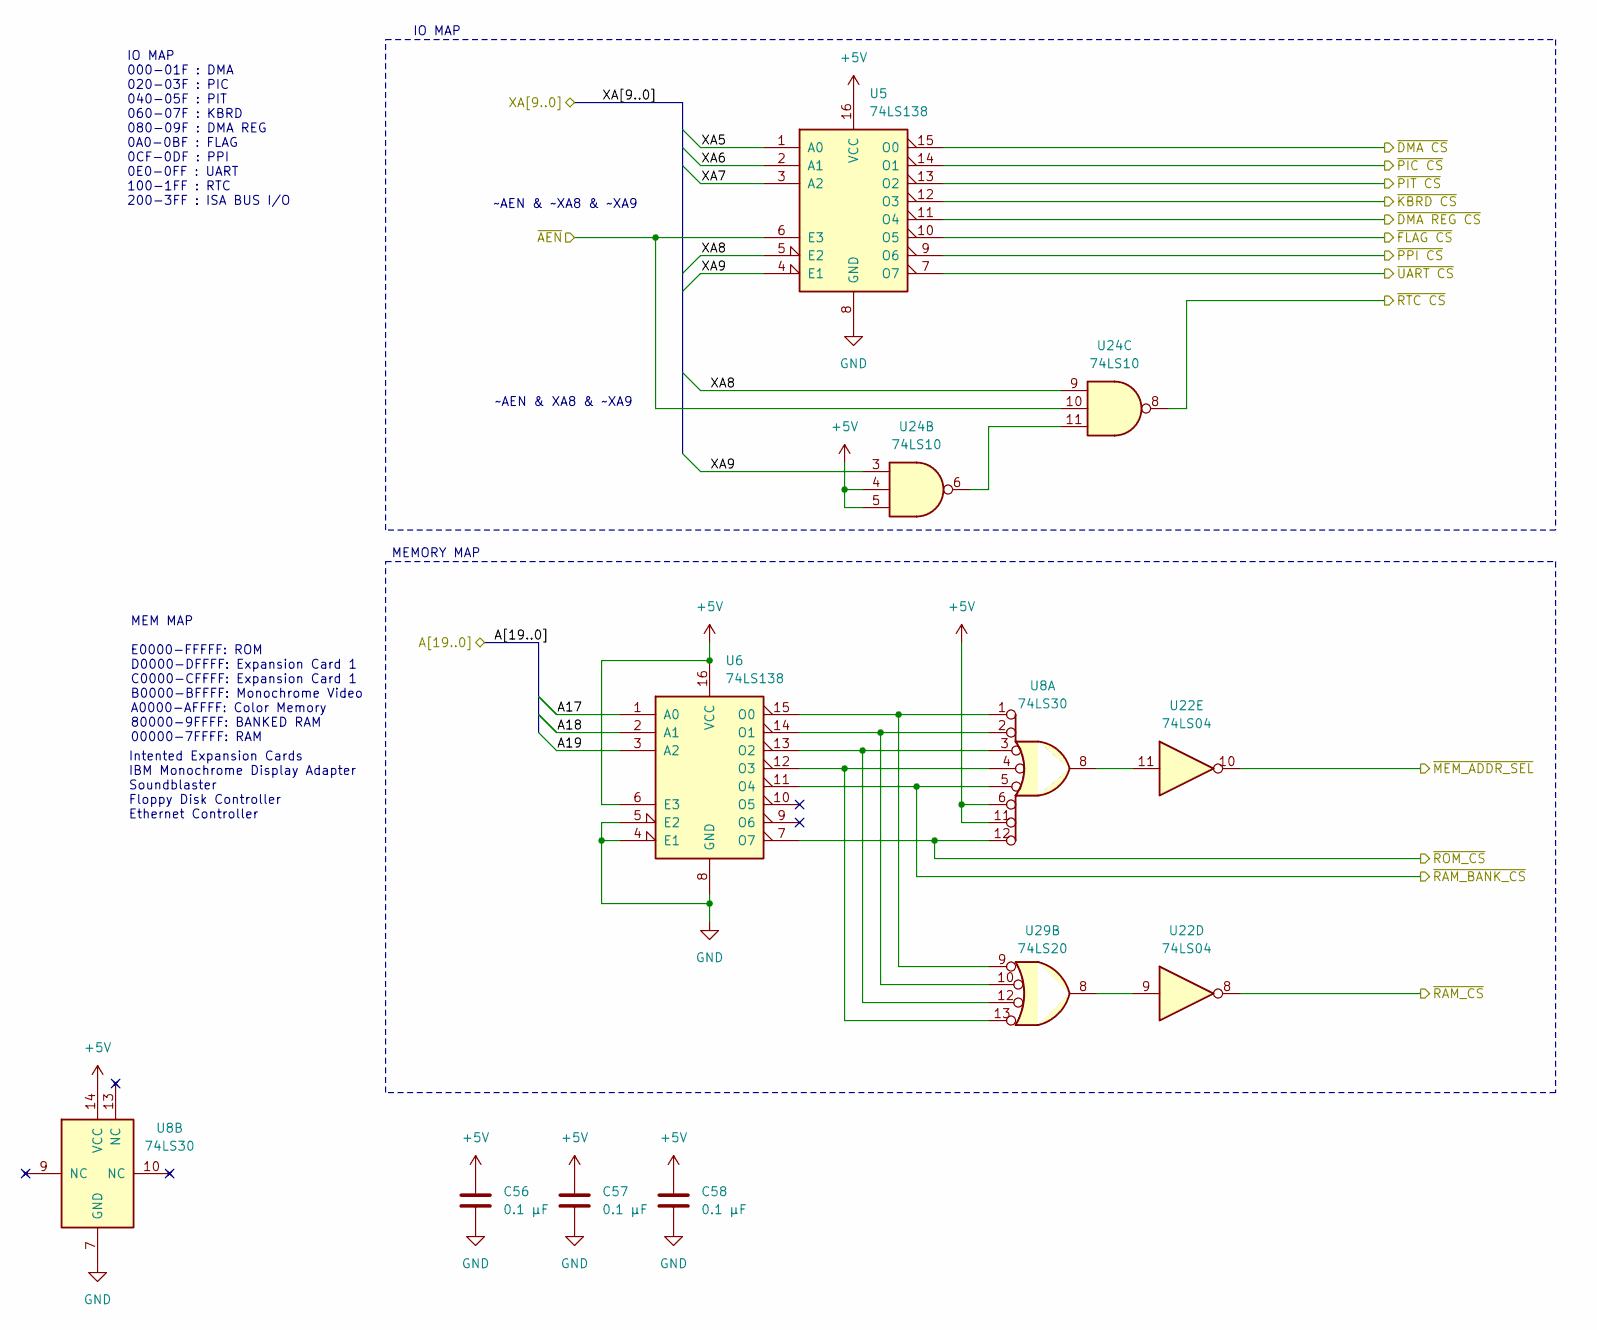
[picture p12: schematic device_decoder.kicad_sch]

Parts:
C56, C57, C58: 0.1 μF; C_1210_3225Metric_Pad1.33x2.70mm_HandSolder
U5, U6: 74LS138; DIP-16_W7.62mm_Socket
U8: 74LS30; DIP-14_W7.62mm_Socket
U22: 74LS04; DIP-14_W7.62mm_Socket
U24: 74LS10; DIP-14_W7.62mm_Socket
U29: 74LS20; DIP-14_W7.62mm_Socket

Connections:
+5V: C56.1, C57.1, C58.1, U5.16 (VCC), U6.6 (E3), U6.16 (VCC), U8.6, U8.11, U8.14 (VCC), U24.4, U24.5; also elsewhere on the board
/Bus Driver/A17: U6.1 (A0); also elsewhere on the board
/Bus Driver/A18: U6.2 (A1); also elsewhere on the board
/Bus Driver/A19: U6.3 (A2); also elsewhere on the board
/Bus Driver/XA5: U5.1 (A0); also elsewhere on the board
/Bus Driver/XA6: U5.2 (A1); also elsewhere on the board
/Bus Driver/XA7: U5.3 (A2); also elsewhere on the board
/Bus Driver/XA8: U5.5 (E2), U24.9; also elsewhere on the board
/Bus Driver/XA9: U5.4 (E1), U24.3; also elsewhere on the board
/Device Decoder/~AEN: U5.6 (E3), U24.10; also elsewhere on the board
/Device Decoder/~MEM_ADDR_SEL: U22.10; also elsewhere on the board
/Device Decoder/~PIC CS: U5.14 (O1); also elsewhere on the board
/Device Decoder/~RAM_BANK_CS: U6.11 (O4), U8.5; also elsewhere on the board
/Device Decoder/~RAM_CS: U22.8; also elsewhere on the board
/Device Decoder/~ROM_CS: U6.7 (O7), U8.12; also elsewhere on the board
/~CS0: U5.15 (O0); also elsewhere on the board
/~CS1: U5.13 (O2); also elsewhere on the board
/~CS2: U5.12 (O3); also elsewhere on the board
/~CS3: U5.11 (O4); also elsewhere on the board
/~CS4: U5.10 (O5); also elsewhere on the board
/~CS5: U5.9 (O6); also elsewhere on the board
/~CS6: U5.7 (O7); also elsewhere on the board
/~CS7: U24.8; also elsewhere on the board
GND: C56.2, C57.2, C58.2, U5.8 (GND), U6.4 (E1), U6.5 (E2), U6.8 (GND), U8.7 (GND); also elsewhere on the board
unnamed: U6.15 (O0), U8.1, U29.9
unnamed: U6.14 (O1), U8.2, U29.10
unnamed: U6.13 (O2), U8.3, U29.12
unnamed: U6.12 (O3), U8.4, U29.13
unnamed: U22.9, U29.8
unnamed: U8.8, U22.11
unnamed: U24.6, U24.11

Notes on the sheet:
~AEN & XA8 & ~XA9
MEMORY MAP
Intented Expansion Cards IBM Monochrome Display Adapter Soundblaster Floppy Disk Controller Ethernet Controller
MEM MAP E0000-FFFFF: ROM D0000-DFFFF: Expansion Card 1 C0000-CFFFF: Expansion Card 1 B0000-BFFFF: Monochrome Video A0000-AFFFF: Color Memory 80000-9FFFF: BANKED RAM 00000-7FFFF: RAM
~AEN & ~XA8 & ~XA9
IO MAP 000-01F : DMA 020-03F : PIC 040-05F : PIT 060-07F : KBRD 080-09F : DMA REG 0A0-0BF : FLAG 0CF-0DF : PPI 0E0-0FF : UART 100-1FF : RTC 200-3FF : ISA BUS I/O
IO MAP

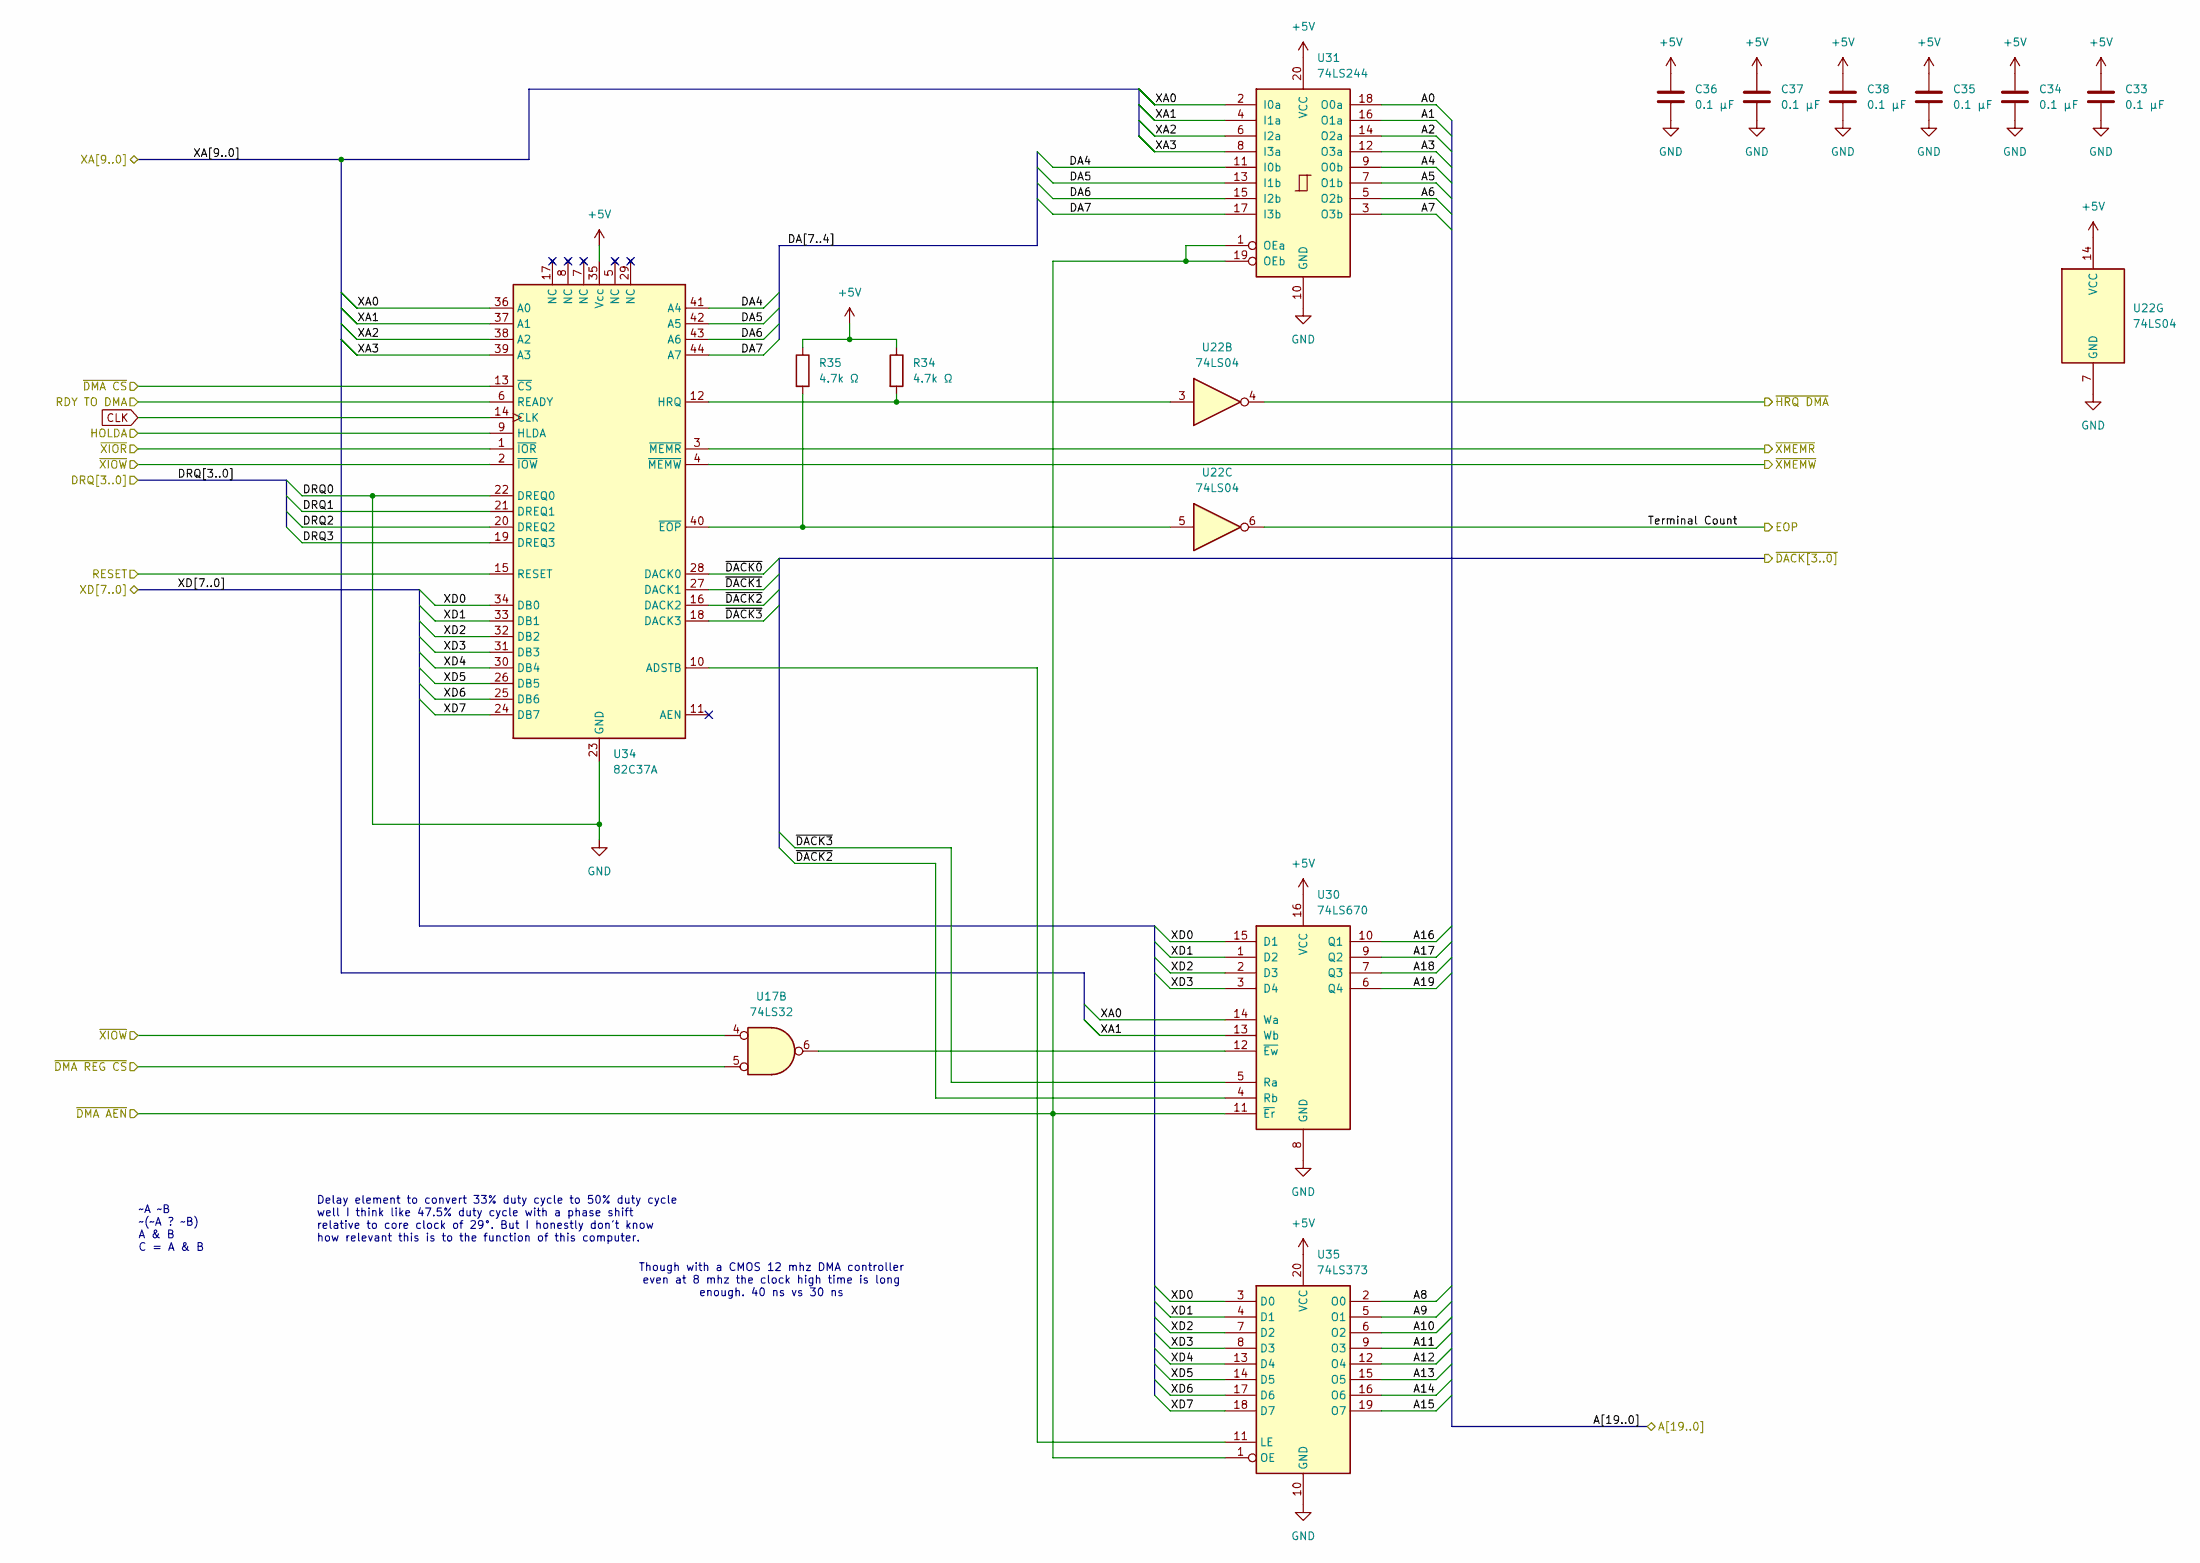
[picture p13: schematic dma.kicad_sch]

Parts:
C33, C34, C35, C36, C37, C38: 0.1 μF; C_1210_3225Metric_Pad1.33x2.70mm_HandSolder
R34, R35: 4.7k Ω; R_1206_3216Metric_Pad1.30x1.75mm_HandSolder
U17: 74LS32; DIP-14_W7.62mm_Socket
U22: 74LS04; DIP-14_W7.62mm_Socket
U30: 74LS670; DIP-16_W7.62mm_Socket
U31: 74LS244; DIP-20_W7.62mm_Socket
U34: 82C37A; PLCC-44_THT-Socket
U35: 74LS373; DIP-20_W7.62mm_Socket

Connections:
+5V: C33.1, C34.1, C35.1, C36.1, C37.1, C38.1, R34.1, R35.1, U22.14 (VCC), U30.16 (VCC), U31.20 (VCC), U34.35 (Vcc), U35.20 (VCC); also elsewhere on the board
/Bus Driver/A0: U31.18 (O0a); also elsewhere on the board
/Bus Driver/A1: U31.16 (O1a); also elsewhere on the board
/Bus Driver/A2: U31.14 (O2a); also elsewhere on the board
/Bus Driver/A3: U31.12 (O3a); also elsewhere on the board
/Bus Driver/A4: U31.9 (O0b); also elsewhere on the board
/Bus Driver/A5: U31.7 (O1b); also elsewhere on the board
/Bus Driver/A6: U31.5 (O2b); also elsewhere on the board
/Bus Driver/A7: U31.3 (O3b); also elsewhere on the board
/Bus Driver/A8: U35.2 (O0); also elsewhere on the board
/Bus Driver/A9: U35.5 (O1); also elsewhere on the board
/Bus Driver/A10: U35.6 (O2); also elsewhere on the board
/Bus Driver/A11: U35.9 (O3); also elsewhere on the board
/Bus Driver/A12: U35.12 (O4); also elsewhere on the board
/Bus Driver/A13: U35.15 (O5); also elsewhere on the board
/Bus Driver/A14: U35.16 (O6); also elsewhere on the board
/Bus Driver/A15: U35.19 (O7); also elsewhere on the board
/Bus Driver/A16: U30.10 (Q1); also elsewhere on the board
/Bus Driver/A17: U30.9 (Q2); also elsewhere on the board
/Bus Driver/A18: U30.7 (Q3); also elsewhere on the board
/Bus Driver/A19: U30.6 (Q4); also elsewhere on the board
/Bus Driver/RESET: U34.15 (RESET); also elsewhere on the board
/Bus Driver/XA0: U30.14 (Wa), U31.2 (I0a), U34.36 (A0); also elsewhere on the board
/Bus Driver/XA1: U30.13 (Wb), U31.4 (I1a), U34.37 (A1); also elsewhere on the board
/Bus Driver/XA2: U31.6 (I2a), U34.38 (A2); also elsewhere on the board
/Bus Driver/XA3: U31.8 (I3a), U34.39 (A3); also elsewhere on the board
/Bus Driver/XD0: U30.15 (D1), U34.34 (DB0), U35.3 (D0); also elsewhere on the board
/Bus Driver/XD1: U30.1 (D2), U34.33 (DB1), U35.4 (D1); also elsewhere on the board
/Bus Driver/XD2: U30.2 (D3), U34.32 (DB2), U35.7 (D2); also elsewhere on the board
/Bus Driver/XD3: U30.3 (D4), U34.31 (DB3), U35.8 (D3); also elsewhere on the board
/Bus Driver/XD4: U34.30 (DB4), U35.13 (D4); also elsewhere on the board
/Bus Driver/XD5: U34.26 (DB5), U35.14 (D5); also elsewhere on the board
/Bus Driver/XD6: U34.25 (DB6), U35.17 (D6); also elsewhere on the board
/Bus Driver/XD7: U34.24 (DB7), U35.18 (D7); also elsewhere on the board
/Bus Driver/~DMA AEN: U30.11 (~Er), U31.1 (OEa), U31.19 (OEb), U35.1 (OE); also elsewhere on the board
/DMA/DA4: U31.11 (I0b), U34.41 (A4)
/DMA/DA5: U31.13 (I1b), U34.42 (A5)
/DMA/DA6: U31.15 (I2b), U34.43 (A6)
/DMA/DA7: U31.17 (I3b), U34.44 (A7)
/DMA/DRQ1: U34.21 (DREQ1); also elsewhere on the board
/DMA/DRQ2: U34.20 (DREQ2); also elsewhere on the board
/DMA/DRQ3: U34.19 (DREQ3); also elsewhere on the board
/DMA/RDY TO DMA: U34.6 (READY); also elsewhere on the board
/DMA/Terminal Count: U22.6; also elsewhere on the board
/DMA/~DACK0: U34.28 (DACK0); also elsewhere on the board
/DMA/~DACK1: U34.27 (DACK1); also elsewhere on the board
/DMA/~DACK2: U30.4 (Rb), U34.16 (DACK2); also elsewhere on the board
/DMA/~DACK3: U30.5 (Ra), U34.18 (DACK3); also elsewhere on the board
/DMA/~HRQ DMA: U22.4; also elsewhere on the board
/Wait State Generator/HOLDA: U34.9 (HLDA); also elsewhere on the board
/~CS0: U34.13 (~CS); also elsewhere on the board
/~CS3: U17.5; also elsewhere on the board
/~XIOR: U34.1 (~IOR); also elsewhere on the board
/~XIOW: U17.4, U34.2 (~IOW); also elsewhere on the board
/~XMEMR: U34.3 (~MEMR); also elsewhere on the board
/~XMEMW: U34.4 (~MEMW); also elsewhere on the board
CLK: U34.14 (CLK); also elsewhere on the board
GND: C33.2, C34.2, C35.2, C36.2, C37.2, C38.2, U22.7 (GND), U30.8 (GND), U31.10 (GND), U34.22 (DREQ0), U34.23 (GND), U35.10 (GND); also elsewhere on the board
unnamed: U17.6, U30.12 (~Ew)
unnamed: U34.10 (ADSTB), U35.11 (LE)
unnamed: R34.2, U22.3, U34.12 (HRQ)
unnamed: R35.2, U22.5, U34.40 (~EOP)

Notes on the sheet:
Delay element to convert 33% duty cycle to 50% duty cycle well I think like 47.5% duty cycle with a phase shift relative to core clock of 29°. But I honestly don't know how relevant this is to the function of this computer.
Though with a CMOS 12 mhz DMA controller even at 8 mhz the clock high time is long enough. 40 ns vs 30 ns
~A ~B ~(~A ? ~B) A & B C = A & B

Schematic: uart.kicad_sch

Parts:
C52, C67, C68, C69: 1 μF; C_1210_3225Metric_Pad1.33x2.70mm_HandSolder
C72, C73: 0.1 μF; C_1210_3225Metric_Pad1.33x2.70mm_HandSolder
J5: DE9_Socket; L717SDE09PA4CH4RC309
U42: 16550; DIP-40_W15.24mm_Socket
U43: MAX232; DIP-16_W7.62mm_Socket

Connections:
+5V: C72.1, C73.1, U42.12 (CS0), U42.13 (CS1), U42.39 (~RI), U42.40 (VCC), U43.16 (VCC); also elsewhere on the board
/Bus Driver/RESET: U42.35 (MR); also elsewhere on the board
/Bus Driver/XA0: U42.28 (A0); also elsewhere on the board
/Bus Driver/XA1: U42.27 (A1); also elsewhere on the board
/Bus Driver/XA2: U42.26 (A2); also elsewhere on the board
/Bus Driver/XD0: U42.1 (D0); also elsewhere on the board
/Bus Driver/XD1: U42.2 (D1); also elsewhere on the board
/Bus Driver/XD2: U42.3 (D2); also elsewhere on the board
/Bus Driver/XD3: U42.4 (D3); also elsewhere on the board
/Bus Driver/XD4: U42.5 (D4); also elsewhere on the board
/Bus Driver/XD5: U42.6 (D5); also elsewhere on the board
/Bus Driver/XD6: U42.7 (D6); also elsewhere on the board
/Bus Driver/XD7: U42.8 (D7); also elsewhere on the board
/Processor And Control/IRQ4: U42.30 (INTR); also elsewhere on the board
/UART/CTS: J5.8, U43.8 (R2IN)
/UART/RTS: J5.7, U43.7 (T2OUT)
/UART/RXD: J5.2, U43.14 (T1OUT)
/UART/TXD: J5.3, U43.13 (R1IN)
/~CS6: U42.14 (~CS2); also elsewhere on the board
/~XIOR: U42.21 (~RD); also elsewhere on the board
/~XIOW: U42.18 (~WR); also elsewhere on the board
CLK: U42.16 (XIN); also elsewhere on the board
GND: C68.2, C69.2, C72.2, C73.2, J5.5, J5.MH1, J5.MH2, U42.19 (WR), U42.20 (GND), U42.22 (RD), U42.25 (~ADS), U43.15 (GND); also elsewhere on the board
unnamed: U42.9 (RCLK), U42.15 (~BAUDOUT)
unnamed: U42.10 (SIN), U43.12 (R1OUT)
unnamed: U42.11 (SOUT), U43.11 (T1IN)
unnamed: U42.36 (~CTS), U43.9 (R2OUT)
unnamed: U42.32 (~RTS), U43.10 (T2IN)
unnamed: C52.1, U43.1 (C1+)
unnamed: C52.2, U43.3 (C1-)
unnamed: C67.1, U43.4 (C2+)
unnamed: C67.2, U43.5 (C2-)
unnamed: C69.1, U43.2 (VS+)
unnamed: C68.1, U43.6 (VS-)

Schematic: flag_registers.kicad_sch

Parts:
C76, C77, C78, C79, C80: 0.1 μF; C_1210_3225Metric_Pad1.33x2.70mm_HandSolder
U17: 74LS32; DIP-14_W7.62mm_Socket
U54: 74LS273; DIP-20_W7.62mm_Socket
U55: 74LS244; DIP-20_W7.62mm_Socket

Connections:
+5V: C76.1, C77.1, C78.1, C79.1, C80.1, U17.14 (VCC), U54.20 (VCC), U55.20 (VCC); also elsewhere on the board
/Bus Driver/XD0: U54.3 (D0), U55.18 (O0a); also elsewhere on the board
/Bus Driver/XD1: U54.4 (D1), U55.16 (O1a); also elsewhere on the board
/Bus Driver/XD2: U54.7 (D2), U55.14 (O2a); also elsewhere on the board
/Bus Driver/XD3: U54.8 (D3), U55.12 (O3a); also elsewhere on the board
/Bus Driver/XD4: U54.13 (D4), U55.9 (O0b); also elsewhere on the board
/Bus Driver/XD5: U54.14 (D5), U55.7 (O1b); also elsewhere on the board
/Bus Driver/XD6: U54.17 (D6), U55.5 (O2b); also elsewhere on the board
/Bus Driver/XD7: U54.18 (D7), U55.3 (O3b); also elsewhere on the board
/Flag Registers/ALLOW NMI: U54.19 (Q7), U55.17 (I3b); also elsewhere on the board
/Flag Registers/BA0: U54.2 (Q0), U55.2 (I0a); also elsewhere on the board
/Flag Registers/BA1: U54.5 (Q1), U55.4 (I1a); also elsewhere on the board
/Flag Registers/ENABLE IO CK: U54.16 (Q6), U55.15 (I2b); also elsewhere on the board
/Flag Registers/I/O CH CK: U55.11 (I0b); also elsewhere on the board
/Flag Registers/SPKR EN: U54.6 (Q2), U55.6 (I2a); also elsewhere on the board
/Flag Registers/SPKR GATE: U54.9 (Q3), U55.8 (I3a); also elsewhere on the board
/Flag Registers/SPKR OUT: U55.13 (I1b); also elsewhere on the board
/Wait State Generator/~RESET: U54.1 (~Mr); also elsewhere on the board
/~CS4: U17.9, U17.12; also elsewhere on the board
/~XIOR: U17.13; also elsewhere on the board
/~XIOW: U17.10; also elsewhere on the board
GND: C76.2, C77.2, C78.2, C79.2, C80.2, U17.7 (GND), U54.10 (GND), U55.10 (GND); also elsewhere on the board
unnamed: U17.8, U54.11 (Cp)
unnamed: U17.11, U55.1 (OEa), U55.19 (OEb)

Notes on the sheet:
FLAG REG BIT 0: BANK ADDRESS 0 (R/W) BIT 1: BANK ADDRESS 1 (R/W) BIT 2: SPKR DATA (R/W) BIT 3: PIT GATE SPK (R/W) BIT 4: PIT 2 OUT (R) BIT 5: I/O CH CK (R) BIT 6: Disable IO CK (R/W) BIT 7: Enable NMI (R/W)

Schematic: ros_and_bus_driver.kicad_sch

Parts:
C63, C64, C65, C66: 0.1 μF; C_1210_3225Metric_Pad1.33x2.70mm_HandSolder
R37, R38, R39, R40: 4.7k Ω; R_1206_3216Metric_Pad1.30x1.75mm_HandSolder
R51: 33 Ω; R_1206_3216Metric_Pad1.30x1.75mm_HandSolder
U17: 74LS32; DIP-14_W7.62mm_Socket
U27, U28: 74LS245; DIP-20_W7.62mm_Socket
U48, U56: 74LS244; DIP-20_W7.62mm_Socket

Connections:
+5V: C63.1, C64.1, C65.1, C66.1, R37.1, R38.1, R39.1, R40.1, U27.20 (VCC), U28.20 (VCC), U48.20 (VCC), U56.20 (VCC); also elsewhere on the board
/Bus Driver/A0: U56.2 (I0a); also elsewhere on the board
/Bus Driver/A1: U56.4 (I1a); also elsewhere on the board
/Bus Driver/A2: U56.6 (I2a); also elsewhere on the board
/Bus Driver/A3: U56.8 (I3a); also elsewhere on the board
/Bus Driver/A4: U56.11 (I0b); also elsewhere on the board
/Bus Driver/A5: U56.13 (I1b); also elsewhere on the board
/Bus Driver/A6: U56.15 (I2b); also elsewhere on the board
/Bus Driver/A7: U56.17 (I3b); also elsewhere on the board
/Bus Driver/A8: U48.2 (I0a); also elsewhere on the board
/Bus Driver/A9: U48.4 (I1a); also elsewhere on the board
/Bus Driver/AEN: U48.12 (O3a); also elsewhere on the board
/Bus Driver/D0: U27.2 (A0); also elsewhere on the board
/Bus Driver/D1: U27.3 (A1); also elsewhere on the board
/Bus Driver/D2: U27.4 (A2); also elsewhere on the board
/Bus Driver/D3: U27.5 (A3); also elsewhere on the board
/Bus Driver/D4: U27.6 (A4); also elsewhere on the board
/Bus Driver/D5: U27.7 (A5); also elsewhere on the board
/Bus Driver/D6: U27.8 (A6); also elsewhere on the board
/Bus Driver/D7: U27.9 (A7); also elsewhere on the board
/Bus Driver/RESET: U48.9 (O0b); also elsewhere on the board
/Bus Driver/RESET BRD: U48.11 (I0b); also elsewhere on the board
/Bus Driver/XA0: U56.18 (O0a); also elsewhere on the board
/Bus Driver/XA1: U56.16 (O1a); also elsewhere on the board
/Bus Driver/XA2: U56.14 (O2a); also elsewhere on the board
/Bus Driver/XA3: U56.12 (O3a); also elsewhere on the board
/Bus Driver/XA4: U56.9 (O0b); also elsewhere on the board
/Bus Driver/XA5: U56.7 (O1b); also elsewhere on the board
/Bus Driver/XA6: U56.5 (O2b); also elsewhere on the board
/Bus Driver/XA7: U56.3 (O3b); also elsewhere on the board
/Bus Driver/XA8: U48.18 (O0a); also elsewhere on the board
/Bus Driver/XA9: U17.2, U48.16 (O1a); also elsewhere on the board
/Bus Driver/XD0: U27.18 (B0); also elsewhere on the board
/Bus Driver/XD1: U27.17 (B1); also elsewhere on the board
/Bus Driver/XD2: U27.16 (B2); also elsewhere on the board
/Bus Driver/XD3: U27.15 (B3); also elsewhere on the board
/Bus Driver/XD4: U27.14 (B4); also elsewhere on the board
/Bus Driver/XD5: U27.13 (B5); also elsewhere on the board
/Bus Driver/XD6: U27.12 (B6); also elsewhere on the board
/Bus Driver/XD7: U27.11 (B7); also elsewhere on the board
/Bus Driver/~DMA AEN: U28.1 (A->B); also elsewhere on the board
/Wait State Generator/AEN: U27.19 (CE), U48.8 (I3a), U56.1 (OEa), U56.19 (OEb); also elsewhere on the board
/~IOR: U28.5 (A3); also elsewhere on the board
/~IOW: U28.4 (A2); also elsewhere on the board
/~MEMR: U28.3 (A1); also elsewhere on the board
/~MEMW: U28.2 (A0); also elsewhere on the board
/~XIOR: R37.2, U17.1, U28.15 (B3); also elsewhere on the board
/~XIOW: R38.2, U28.16 (B2); also elsewhere on the board
/~XMEMR: R39.2, U28.17 (B1); also elsewhere on the board
/~XMEMW: R40.2, U28.18 (B0); also elsewhere on the board
CLK: R51.2; also elsewhere on the board
CLK88: U48.6 (I2a); also elsewhere on the board
GND: C63.2, C64.2, C65.2, C66.2, U27.10 (GND), U28.10 (GND), U28.19 (CE), U48.1 (OEa), U48.10 (GND), U48.13 (I1b), U48.15 (I2b), U48.17 (I3b), U48.19 (OEb), U56.10 (GND); also elsewhere on the board
unnamed: U17.3, U27.1 (A->B)
unnamed: R51.1, U48.14 (O2a)

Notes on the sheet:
When an IO read happens we need to read from XD but when XA9 is asserted that's a read from the isa bus so we don't want double drivers
Figure out value of termination resistor?

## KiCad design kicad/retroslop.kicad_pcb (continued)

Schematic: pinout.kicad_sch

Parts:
J7: Conn_02x14_Odd_Even; PinSocket_2x14_P2.54mm_Horizontal
U44: USBLC6-2SC6; SOT-23-6

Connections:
+5V: J7.2, U44.5 (VBUS); also elsewhere on the board
/Pinout/PA0: J7.3; also elsewhere on the board
/Pinout/PA1: J7.5; also elsewhere on the board
/Pinout/PA2: J7.7; also elsewhere on the board
/Pinout/PA3: J7.9; also elsewhere on the board
/Pinout/PA4: J7.4; also elsewhere on the board
/Pinout/PA5: J7.6; also elsewhere on the board
/Pinout/PA6: J7.8; also elsewhere on the board
/Pinout/PA7: J7.10; also elsewhere on the board
/Pinout/PB0: J7.11; also elsewhere on the board
/Pinout/PB1: J7.13; also elsewhere on the board
/Pinout/PB2: J7.15; also elsewhere on the board
/Pinout/PB3: J7.17; also elsewhere on the board
/Pinout/PB4: J7.12; also elsewhere on the board
/Pinout/PB5: J7.14; also elsewhere on the board
/Pinout/PB6: J7.16; also elsewhere on the board
/Pinout/PB7: J7.18; also elsewhere on the board
/Pinout/PC0: J7.19; also elsewhere on the board
/Pinout/PC1: J7.21; also elsewhere on the board
/Pinout/PC2: J7.23; also elsewhere on the board
/Pinout/PC3: J7.25; also elsewhere on the board
/Pinout/PC4: J7.20; also elsewhere on the board
/Pinout/PC5: J7.22; also elsewhere on the board
/Pinout/PC6: J7.24; also elsewhere on the board
/Pinout/PC7: J7.26; also elsewhere on the board
/Pinout/PIT GATE: U44.3 (I/O2); also elsewhere on the board
/Pinout/PIT OUT: U44.1 (I/O1); also elsewhere on the board
GND: J7.1, U44.2 (GND); also elsewhere on the board
unnamed: J7.27, U44.6 (I/O1)
unnamed: J7.28, U44.4 (I/O2)

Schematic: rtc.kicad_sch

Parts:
C17, C18, C51: 0.1 μF; C_1210_3225Metric_Pad1.33x2.70mm_HandSolder
IC1: DS12C887+; DIP1550W53P254L3378H1042Q24N; Mouser Part Number 700-DS12C887
S2: TS02-66-50-BK-260-SCR-D; TS026650BK260SCRD; Mouser Part Number 179-TS026650BK260SCR
U2: 74LS02; DIP-14_W7.62mm_Socket
U37: 74LS04; DIP-14_W7.62mm_Socket
U47: 74LS245; DIP-20_W7.62mm_Socket
U50: 74LS373; DIP-20_W7.62mm_Socket

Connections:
+5V: C17.1, C18.1, C51.1, IC1.18 (~RESET), IC1.24 (VCC), U47.20 (VCC), U50.20 (VCC); also elsewhere on the board
/Bus Driver/XA0: U50.3 (D0); also elsewhere on the board
/Bus Driver/XA1: U50.4 (D1); also elsewhere on the board
/Bus Driver/XA2: U50.7 (D2); also elsewhere on the board
/Bus Driver/XA3: U50.8 (D3); also elsewhere on the board
/Bus Driver/XA4: U50.13 (D4); also elsewhere on the board
/Bus Driver/XA5: U50.14 (D5); also elsewhere on the board
/Bus Driver/XA6: U50.17 (D6); also elsewhere on the board
/Bus Driver/XD0: U47.18 (B0); also elsewhere on the board
/Bus Driver/XD1: U47.17 (B1); also elsewhere on the board
/Bus Driver/XD2: U47.16 (B2); also elsewhere on the board
/Bus Driver/XD3: U47.15 (B3); also elsewhere on the board
/Bus Driver/XD4: U47.14 (B4); also elsewhere on the board
/Bus Driver/XD5: U47.13 (B5); also elsewhere on the board
/Bus Driver/XD6: U47.12 (B6); also elsewhere on the board
/Bus Driver/XD7: U47.11 (B7); also elsewhere on the board
/Processor And Control/IRQ6: U37.2; also elsewhere on the board
/RTC/AD0: IC1.4 (AD0), U47.2 (A0), U50.2 (O0)
/RTC/AD1: IC1.5 (AD1), U47.3 (A1), U50.5 (O1)
/RTC/AD2: IC1.6 (AD2), U47.4 (A2), U50.6 (O2)
/RTC/AD3: IC1.7 (AD3), U47.5 (A3), U50.9 (O3)
/RTC/AD4: IC1.8 (AD4), U47.6 (A4), U50.12 (O4)
/RTC/AD5: IC1.9 (AD5), U47.7 (A5), U50.15 (O5)
/RTC/AD6: IC1.10 (AD6), U47.8 (A6), U50.16 (O6)
/RTC/AD7: IC1.11 (AD7), U47.9 (A7), U50.19 (O7)
/RTC/ADDR EN: U37.5, U50.1 (OE); also elsewhere on the board
/RTC/ADDR LATCH: IC1.14 (AS), U50.11 (LE); also elsewhere on the board
/RTC/DATA EN: U37.6, U47.19 (CE)
/RTC/RTC DIR: U2.4, U47.1 (A->B)
/~CS7: IC1.13 (~CS), U2.6; also elsewhere on the board
/~XIOR: IC1.17 (DS), U2.5; also elsewhere on the board
/~XIOW: IC1.15 (R/~W); also elsewhere on the board
GND: C17.2, C18.2, C51.2, IC1.12 (GND), S2.3 (COM_1), S2.4 (COM_2), U47.10 (GND), U50.10 (GND), U50.18 (D7); also elsewhere on the board
unnamed: IC1.21 (N.C._(~RCLR)), S2.1 (NO_1), S2.2 (NO_2)
unnamed: IC1.19 (~IRQ), U37.1

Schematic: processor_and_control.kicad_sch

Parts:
C5, C6: 47nF; C_1210_3225Metric_Pad1.33x2.70mm_HandSolder
C14: JZ300; Mouser Part Number 768-JZ300
C19, C20, C21, C22, C39, C46, C47, C48, C53, C54: 0.1 μF; C_1210_3225Metric_Pad1.33x2.70mm_HandSolder
R20, R21: 510 Ω; R_1206_3216Metric_Pad1.30x1.75mm_HandSolder
R25, R26, R27, R28, R29, R33, R43: 4.7k Ω; R_1206_3216Metric_Pad1.30x1.75mm_HandSolder
R44, R45, R46, R47, R48, R49, R50, R52: 33 Ω; R_1206_3216Metric_Pad1.30x1.75mm_HandSolder
U13: 8284; DIP-18_W7.62mm_Socket
U14: 8088_Max_Mode; DIP-40_W15.24mm_Socket
U15: 8087; DIP-40_W15.24mm_Socket
U16: 8259A; DIP-28_W15.24mm_Socket
U18, U19, U20: 74LS373; DIP-20_W7.62mm_Socket
U21: 74LS245; DIP-20_W7.62mm_Socket
U23: 8288; DIP-20_W7.62mm_Socket
U24: 74LS10; DIP-14_W7.62mm_Socket
Y2: 14.318 MHz; Crystal_HC49-4H_Vertical

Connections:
+5V: C5.1, C6.1, C19.1, C20.1, C21.1, C22.1, C39.1, C46.1, C47.1, C48.1, C53.1, C54.1, R25.1, R26.1, R27.1, R28.1, R29.1, R33.1, R43.1, U13.7 (~AEN2), U13.18 (VCC), U14.31 (~RQ/~GT0), U14.40 (VCC), U15.33 (~RQ/~GT1), U15.34 (~BHE/S7), U15.40 (VCC), U16.28 (VCC), U18.20 (VCC), U19.20 (VCC), U20.20 (VCC), U21.20 (VCC), U23.20 (VCC), U24.14 (VCC); also elsewhere on the board
/Bus Driver/A0: U20.2 (O0); also elsewhere on the board
/Bus Driver/A1: U20.5 (O1); also elsewhere on the board
/Bus Driver/A2: U20.6 (O2); also elsewhere on the board
/Bus Driver/A3: U20.9 (O3); also elsewhere on the board
/Bus Driver/A4: U20.12 (O4); also elsewhere on the board
/Bus Driver/A5: U20.15 (O5); also elsewhere on the board
/Bus Driver/A6: U20.16 (O6); also elsewhere on the board
/Bus Driver/A7: U20.19 (O7); also elsewhere on the board
/Bus Driver/A8: U19.2 (O0); also elsewhere on the board
/Bus Driver/A9: U19.5 (O1); also elsewhere on the board
/Bus Driver/A10: U19.6 (O2); also elsewhere on the board
/Bus Driver/A11: U19.9 (O3); also elsewhere on the board
/Bus Driver/A12: U19.12 (O4); also elsewhere on the board
/Bus Driver/A13: U19.15 (O5); also elsewhere on the board
/Bus Driver/A14: U19.16 (O6); also elsewhere on the board
/Bus Driver/A15: U19.19 (O7); also elsewhere on the board
/Bus Driver/A16: U18.2 (O0); also elsewhere on the board
/Bus Driver/A17: U18.5 (O1); also elsewhere on the board
/Bus Driver/A18: U18.6 (O2); also elsewhere on the board
/Bus Driver/A19: U18.9 (O3); also elsewhere on the board
/Bus Driver/D0: U21.18 (B0); also elsewhere on the board
/Bus Driver/D1: U21.17 (B1); also elsewhere on the board
/Bus Driver/D2: U21.16 (B2); also elsewhere on the board
/Bus Driver/D3: U21.15 (B3); also elsewhere on the board
/Bus Driver/D4: U21.14 (B4); also elsewhere on the board
/Bus Driver/D5: U21.13 (B5); also elsewhere on the board
/Bus Driver/D6: U21.12 (B6); also elsewhere on the board
/Bus Driver/D7: U21.11 (B7); also elsewhere on the board
/Bus Driver/RESET BRD: U13.10 (RESET), U14.21 (RESET), U15.21 (RESET); also elsewhere on the board
/Bus Driver/XA0: U16.27 (A0); also elsewhere on the board
/Device Decoder/~AEN: U23.15 (CEN); also elsewhere on the board
/Device Decoder/~PIC CS: U16.1 (~CS); also elsewhere on the board
/POWER/PWR GOOD: U13.11 (~RES); also elsewhere on the board
/Processor And Control/AX0: U14.16 (AD0), U15.16 (AD0), U16.11 (D0), U20.3 (D0), U21.2 (A0)
/Processor And Control/AX1: U14.15 (AD1), U15.15 (AD1), U16.10 (D1), U20.4 (D1), U21.3 (A1)
/Processor And Control/AX2: U14.14 (AD2), U15.14 (AD2), U16.9 (D2), U20.7 (D2), U21.4 (A2)
/Processor And Control/AX3: U14.13 (AD3), U15.13 (AD3), U16.8 (D3), U20.8 (D3), U21.5 (A3)
/Processor And Control/AX4: U14.12 (AD4), U15.12 (AD4), U16.7 (D4), U20.13 (D4), U21.6 (A4)
/Processor And Control/AX5: U14.11 (AD5), U15.11 (AD5), U16.6 (D5), U20.14 (D5), U21.7 (A5)
/Processor And Control/AX6: U14.10 (AD6), U15.10 (AD6), U16.5 (D6), U20.17 (D6), U21.8 (A6)
/Processor And Control/AX7: U14.9 (AD7), U15.9 (AD7), U16.4 (D7), U20.18 (D7), U21.9 (A7)
/Processor And Control/AX8: U14.8 (A8), U15.8 (AD8), U19.3 (D0)
/Processor And Control/AX9: U14.7 (A9), U15.7 (AD9), U19.4 (D1)
/Processor And Control/AX10: U14.6 (A10), U15.6 (AD10), U19.7 (D2)
/Processor And Control/AX11: U14.5 (A11), U15.5 (AD11), U19.8 (D3)
/Processor And Control/AX12: U14.4 (A12), U15.4 (AD12), U19.13 (D4)
/Processor And Control/AX13: U14.3 (A13), U15.3 (AD13), U19.14 (D5)
/Processor And Control/AX14: U14.2 (A14), U15.2 (AD14), U19.17 (D6)
/Processor And Control/AX15: U14.39 (A15), U15.39 (AD15), U19.18 (D7)
/Processor And Control/AX16: U14.38 (A16/S3), U15.38 (A16/S3), U18.3 (D0)
/Processor And Control/AX17: U14.37 (A17/S4), U15.37 (A17/S4), U18.4 (D1)
/Processor And Control/AX18: U14.36 (A18/S5), U15.36 (A18/S5), U18.7 (D2)
/Processor And Control/AX19: U14.35 (A19/S6), U15.35 (A19/S6), U18.8 (D3)
/Processor And Control/FPU IRQ: U15.32 (INT); also elsewhere on the board
/Processor And Control/IRQ0: U16.18 (IR0); also elsewhere on the board
/Processor And Control/IRQ1: U16.19 (IR1); also elsewhere on the board
/Processor And Control/IRQ2: U16.20 (IR2); also elsewhere on the board
/Processor And Control/IRQ3: U16.21 (IR3); also elsewhere on the board
/Processor And Control/IRQ4: U16.22 (IR4); also elsewhere on the board
/Processor And Control/IRQ5: U16.23 (IR5); also elsewhere on the board
/Processor And Control/IRQ6: U16.24 (IR6); also elsewhere on the board
/Processor And Control/IRQ7: U16.25 (IR7); also elsewhere on the board
/Processor And Control/NMI: U14.17 (NMI); also elsewhere on the board
/Processor And Control/QS1: U14.24 (QS1), U15.24 (QS1)
/Processor And Control/QSO: U14.25 (QS0), U15.25 (QS0)
/Processor And Control/~DMA WAIT: U13.4 (RDY1); also elsewhere on the board
/Processor And Control/~LOCK: U14.29 (~LOCK); also elsewhere on the board
/Processor And Control/~S0: U14.26 (~S0), U15.26 (~S0), U23.19 (~S0); also elsewhere on the board
/Processor And Control/~S1: U14.27 (~S1), U15.27 (~S1), U23.3 (~S1); also elsewhere on the board
/Processor And Control/~S2: U14.28 (~S2), U15.28 (~S2), U23.18 (~S2); also elsewhere on the board
/RTC/ADDR EN: U23.16 (DEN), U24.1; also elsewhere on the board
/RTC/ADDR LATCH: R52.2, U18.11 (LE), U19.11 (LE), U20.11 (LE); also elsewhere on the board
/Wait State Generator/AEN: U18.1 (OE), U19.1 (OE), U20.1 (OE), U23.6 (~AEN); also elsewhere on the board
/Wait State Generator/~RDY/WAIT: U13.3 (~AEN1); also elsewhere on the board
/~IOR: R28.2, R47.2; also elsewhere on the board
/~IOW: R25.2, R44.2; also elsewhere on the board
/~MEMR: R27.2, R46.2; also elsewhere on the board
/~MEMW: R26.2, R45.2; also elsewhere on the board
/~XIOR: U16.3 (~RD); also elsewhere on the board
/~XIOW: U16.2 (~WR); also elsewhere on the board
CLK: U23.2 (CLK); also elsewhere on the board
CLK88: R50.2, U14.19 (CLK), U15.19 (CLK); also elsewhere on the board
GND: C5.2, C6.2, C19.2, C20.2, C21.2, C22.2, C39.2, C46.2, C47.2, C48.2, C53.2, C54.2, R20.2, R21.2, U13.1 (CSYNC), U13.6 (RDY2), U13.9 (GND), U13.13 (F/~C), U13.15 (~ASYNC), U14.1 (GND), U14.20 (GND), U14.33 (MN/~MX), U15.1 (GND), U15.20 (GND), U16.14 (GND), U18.10 (GND), U18.13 (D4), U18.14 (D5), U18.17 (D6), U18.18 (D7), U19.10 (GND), U20.10 (GND), U21.10 (GND), U23.1 (IOB), U23.10 (GND), U24.7 (GND); also elsewhere on the board
unnamed: C14.2 (COLD(ROTOR)_TERMINAL), R20.1, U13.17 (X1)
unnamed: C14.1 (HOT-END_TERMINAL), Y2.2
unnamed: R50.1, U13.8 (CLK)
unnamed: R49.1, U13.12 (OSC)
unnamed: R48.1, U13.2 (PCLK)
unnamed: U13.5 (READY), U14.22 (READY), U15.22 (READY)
unnamed: R21.1, U13.16 (X2), Y2.1
unnamed: U14.18 (INTR), U16.17 (INT)
unnamed: R43.2, U14.30 (~RQ/~GT1), U15.31 (~RQ/~GT0)
unnamed: R33.2, U14.23 (~TEST), U15.23 (BUSY)
unnamed: U16.26 (~INTA), U23.14 (~INTA)
unnamed: R29.2, U16.16 (~SP/~EN), U24.2, U24.13
unnamed: U21.1 (A->B), U23.4 (DT/~R)
unnamed: U21.19 (CE), U24.12
unnamed: R52.1, U23.5 (ALE)
unnamed: R44.1, U23.12 (~AIOWC)
unnamed: R45.1, U23.8 (~AMWC)
unnamed: R47.1, U23.13 (~IORC)
unnamed: R46.1, U23.7 (~MRDC)
OSC: R49.2; also elsewhere on the board
PCLK: R48.2; also elsewhere on the board

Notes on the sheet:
Figure out termination resistor values?
PROCESSOR AND COPROCESSOR
INTERRUPT CONTROLLER
CLOCK
Bus Control
IRQ0: RTC Interrupt IRQ1: Keyboard Interrupt IRQ2: Peripheral IRQ3: Peripheral IRQ4: Serial Port 1 (Internal) IRQ5: Peripheral IRQ6: RTC IRQ IRQ7: Mouse Interrupt

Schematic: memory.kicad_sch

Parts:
C29, C30, C31, C32: 0.1 μF; C_1210_3225Metric_Pad1.33x2.70mm_HandSolder
U7, U12: AS6C4008-55PCN; DIP-32_W15.24mm_Socket
U9: 74LS245; DIP-20_W7.62mm_Socket
U26: SST39SF010; DIP_Socket-32_W11.9mm_W12.7mm_W15.24mm_W17.78mm_W18.5mm_3M_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

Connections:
+5V: C29.1, C30.1, C31.1, C32.1, U7.32 (VCC), U9.20 (VCC), U12.32 (VCC), U26.31 (PGM), U26.32 (VCC); also elsewhere on the board
/Bus Driver/A0: U7.12 (A0), U12.12 (A0), U26.12 (A0); also elsewhere on the board
/Bus Driver/A1: U7.11 (A1), U12.11 (A1), U26.11 (A1); also elsewhere on the board
/Bus Driver/A2: U7.10 (A2), U12.10 (A2), U26.10 (A2); also elsewhere on the board
/Bus Driver/A3: U7.9 (A3), U12.9 (A3), U26.9 (A3); also elsewhere on the board
/Bus Driver/A4: U7.8 (A4), U12.8 (A4), U26.8 (A4); also elsewhere on the board
/Bus Driver/A5: U7.7 (A5), U12.7 (A5), U26.7 (A5); also elsewhere on the board
/Bus Driver/A6: U7.6 (A6), U12.6 (A6), U26.6 (A6); also elsewhere on the board
/Bus Driver/A7: U7.5 (A7), U12.5 (A7), U26.5 (A7); also elsewhere on the board
/Bus Driver/A8: U7.27 (A8), U12.27 (A8), U26.27 (A8); also elsewhere on the board
/Bus Driver/A9: U7.26 (A9), U12.26 (A9), U26.26 (A9); also elsewhere on the board
/Bus Driver/A10: U7.23 (A10), U12.23 (A10), U26.23 (A10); also elsewhere on the board
/Bus Driver/A11: U7.25 (A11), U12.25 (A11), U26.25 (A11); also elsewhere on the board
/Bus Driver/A12: U7.4 (A12), U12.4 (A12), U26.4 (A12); also elsewhere on the board
/Bus Driver/A13: U7.28 (A13), U12.28 (A13), U26.28 (A13); also elsewhere on the board
/Bus Driver/A14: U7.3 (A14), U12.3 (A14), U26.29 (A14); also elsewhere on the board
/Bus Driver/A15: U7.31 (A15), U12.31 (A15), U26.3 (A15); also elsewhere on the board
/Bus Driver/A16: U7.2 (A16), U12.2 (A16), U26.2 (A16); also elsewhere on the board
/Bus Driver/A17: U7.30 (A17); also elsewhere on the board
/Bus Driver/A18: U7.1 (A18); also elsewhere on the board
/Bus Driver/D0: U9.2 (A0); also elsewhere on the board
/Bus Driver/D1: U9.3 (A1); also elsewhere on the board
/Bus Driver/D2: U9.4 (A2); also elsewhere on the board
/Bus Driver/D3: U9.5 (A3); also elsewhere on the board
/Bus Driver/D4: U9.6 (A4); also elsewhere on the board
/Bus Driver/D5: U9.7 (A5); also elsewhere on the board
/Bus Driver/D6: U9.8 (A6); also elsewhere on the board
/Bus Driver/D7: U9.9 (A7); also elsewhere on the board
/Device Decoder/~MEM_ADDR_SEL: U9.19 (CE); also elsewhere on the board
/Device Decoder/~RAM_BANK_CS: U12.22 (CE#); also elsewhere on the board
/Device Decoder/~RAM_CS: U7.22 (CE#); also elsewhere on the board
/Device Decoder/~ROM_CS: U26.22 (CE); also elsewhere on the board
/Flag Registers/BA0: U12.30 (A17); also elsewhere on the board
/Flag Registers/BA1: U12.1 (A18); also elsewhere on the board
/RAM and ROM/MD0: U7.13 (DQ0), U9.18 (B0), U12.13 (DQ0), U26.13 (D0)
/RAM and ROM/MD1: U7.14 (DQ1), U9.17 (B1), U12.14 (DQ1), U26.14 (D1)
/RAM and ROM/MD2: U7.15 (DQ2), U9.16 (B2), U12.15 (DQ2), U26.15 (D2)
/RAM and ROM/MD3: U7.17 (DQ3), U9.15 (B3), U12.17 (DQ3), U26.17 (D3)
/RAM and ROM/MD4: U7.18 (DQ4), U9.14 (B4), U12.18 (DQ4), U26.18 (D4)
/RAM and ROM/MD5: U7.19 (DQ5), U9.13 (B5), U12.19 (DQ5), U26.19 (D5)
/RAM and ROM/MD6: U7.20 (DQ6), U9.12 (B6), U12.20 (DQ6), U26.20 (D6)
/RAM and ROM/MD7: U7.21 (DQ7), U9.11 (B7), U12.21 (DQ7), U26.21 (D7)
/~XMEMR: U7.24 (OE#), U9.1 (A->B), U12.24 (OE#), U26.24 (OE); also elsewhere on the board
/~XMEMW: U7.29 (WE#), U12.29 (WE#); also elsewhere on the board
GND: C29.2, C30.2, C31.2, C32.2, U7.16 (VSS), U9.10 (GND), U12.16 (VSS), U26.16 (GND); also elsewhere on the board

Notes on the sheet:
LOWER RAM
ROM
BANKED RAM

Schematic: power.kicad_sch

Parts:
C11, C15, C23, C24: 10 uF; C_1210_3225Metric_Pad1.33x2.70mm_HandSolder
J8: ATX-24; 39-28-1243
J13: Power Jumper; PinHeader_1x02_P2.54mm_Vertical
S1: Power Switch; 1080041EVX; Mouser Part Number 108-0041-EVX

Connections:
+5V: C24.1, J8.4 (+5V), J8.6 (+5V), J8.21 (+5V), J8.22 (+5V), J8.23 (+5V); also elsewhere on the board
+12V: C15.1, J8.10 (+12V), J8.11 (+12V); also elsewhere on the board
-12V: C23.1, J8.14 (-12V); also elsewhere on the board
/POWER/PWR GOOD: C11.1, J8.8 (PWR_OK); also elsewhere on the board
GND: C11.2, C15.2, C23.2, C24.2, J8.3 (GND), J8.5 (GND), J8.7 (GND), J8.15 (GND), J8.17 (GND), J8.18 (GND), J8.19 (GND), J8.24 (GND), J13.2, S1.1 (NC), S1.2 (NOT_CONNECTED); also elsewhere on the board
unnamed: J8.16 (PS_ON#), J13.1, S1.3 (COM)

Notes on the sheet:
SPDT SWITCH

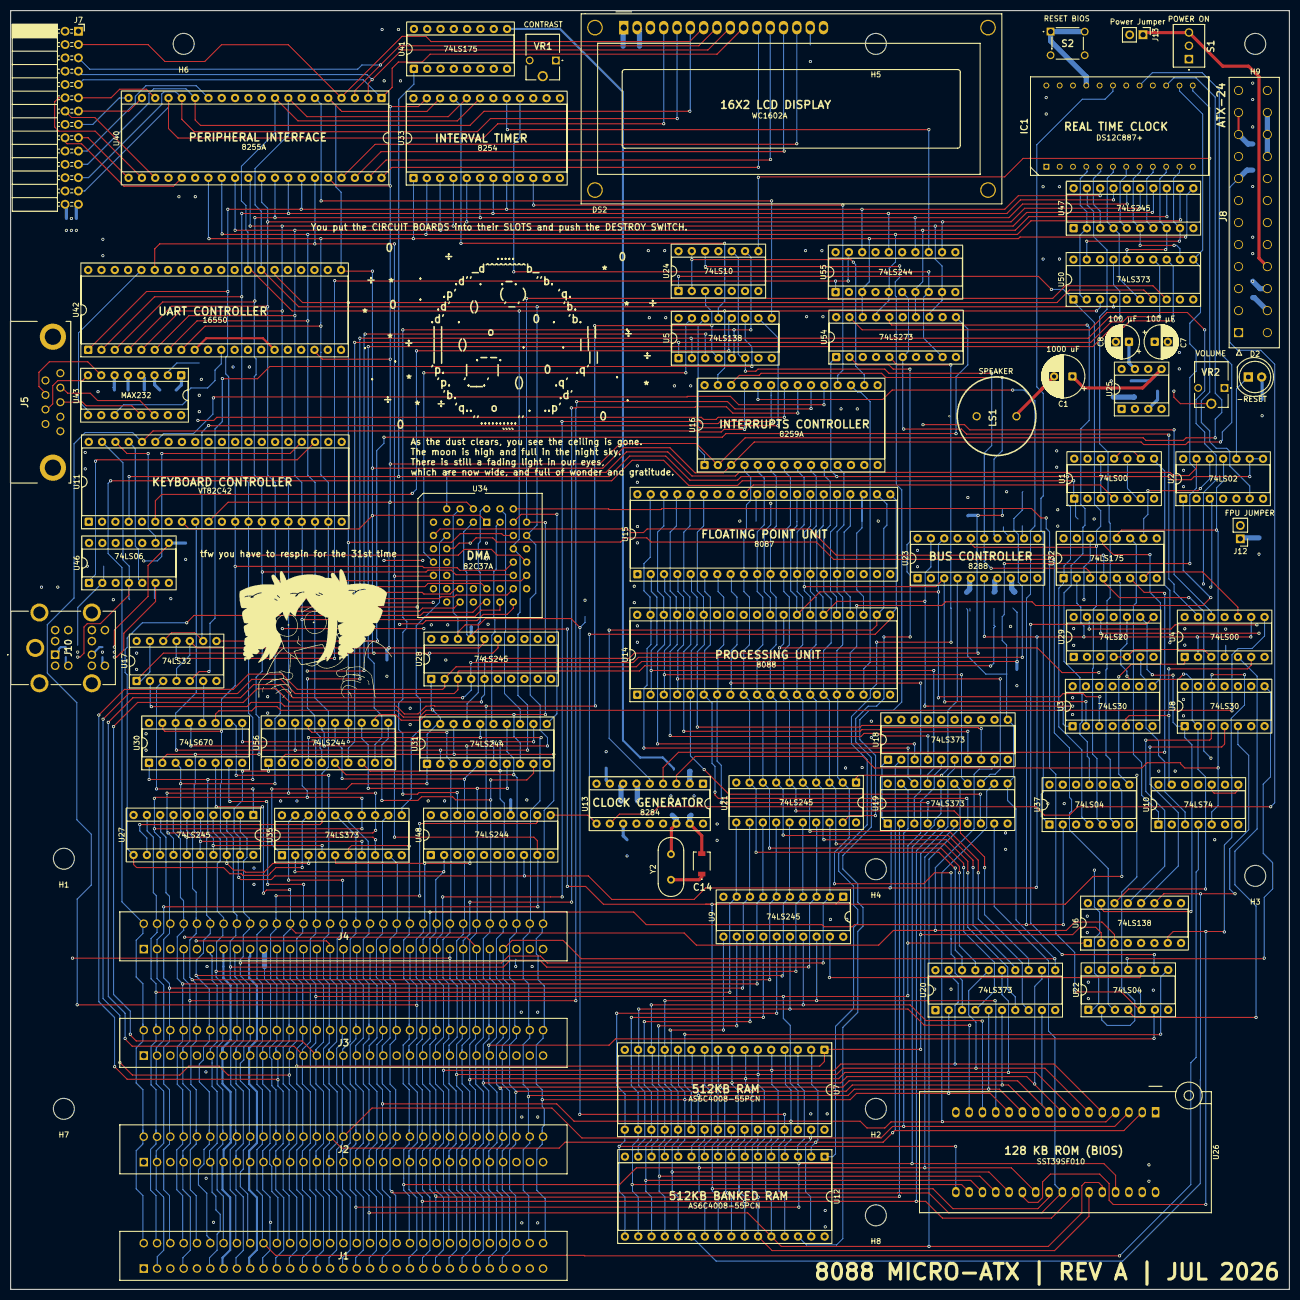
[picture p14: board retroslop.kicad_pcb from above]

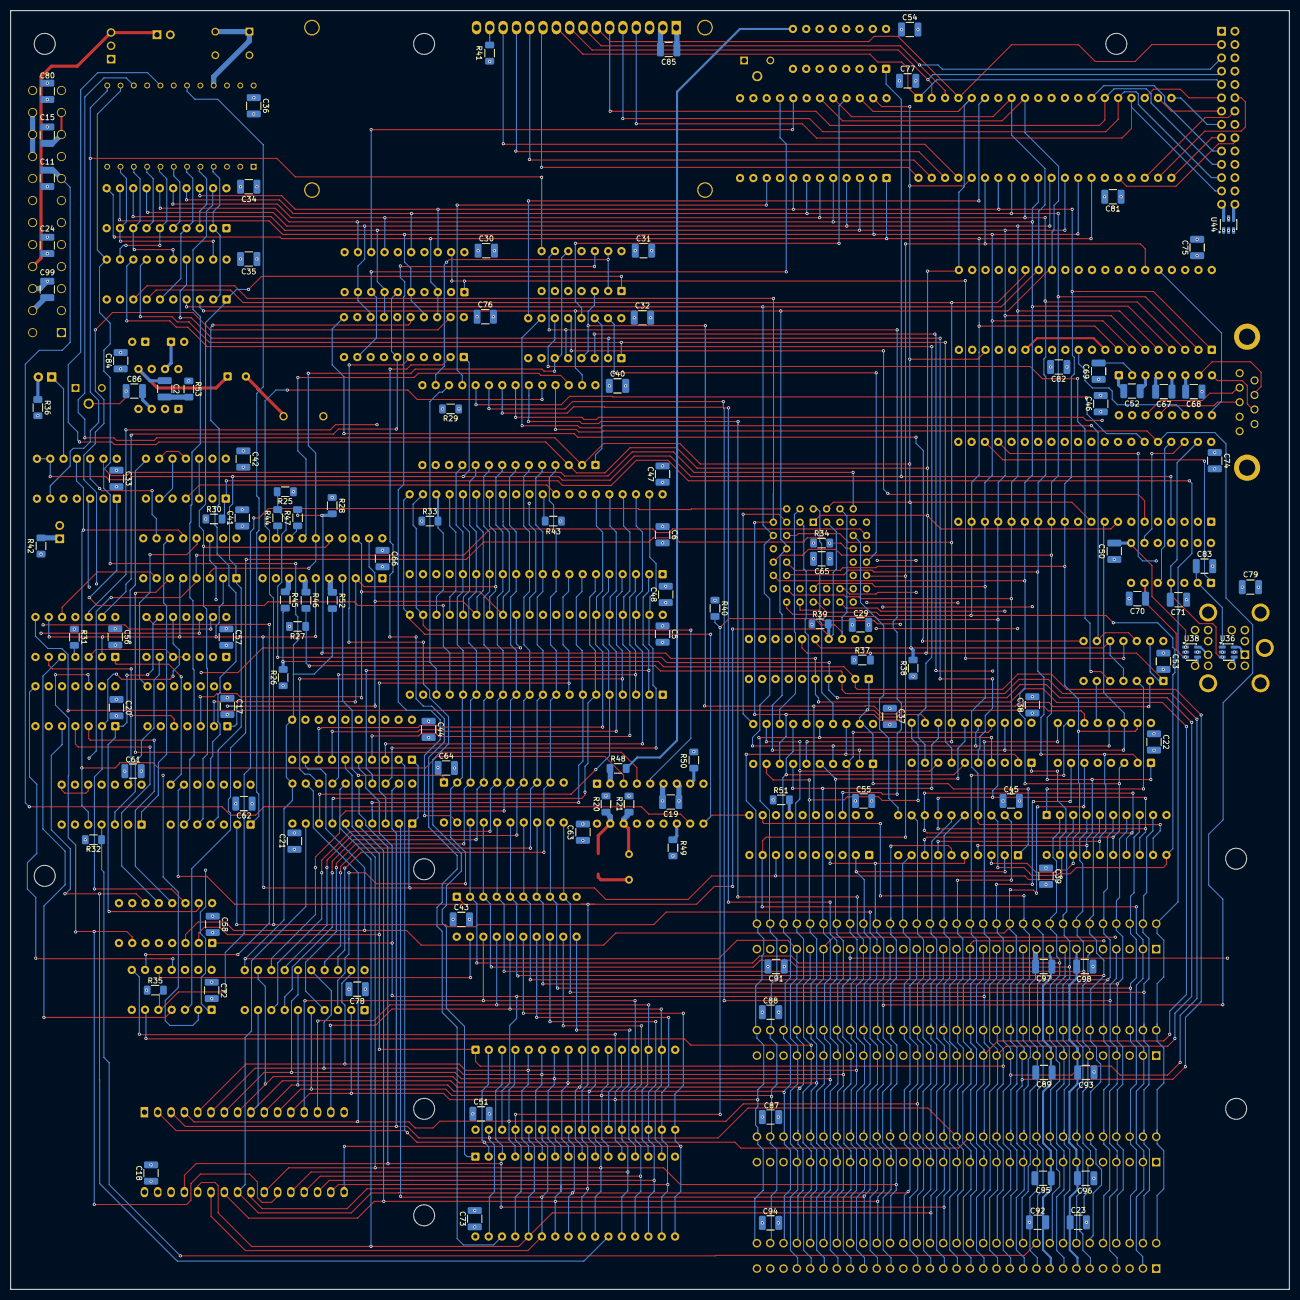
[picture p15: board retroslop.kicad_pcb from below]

Board: 6 copper layers, 244.0 x 244.0 mm, 193 parts (114 on the bottom side), 291 nets.

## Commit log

2026-07-01 Added stuff
    [device_decoder.kicad_sch, dma.kicad_sch, flag_registers.kicad_sch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]
2026-07-02 Progress routing
    [flag_registers.kicad_sch, wait_state_generator.kicad_sch]
2026-07-03 tried manhattan routing
    [retroslop.kicad_sch, wait_state_generator.kicad_sch]
2026-07-04 finished routing rev3
    [device_decoder.kicad_sch, retroslop.kicad_sch, wait_state_generator.kicad_sch]
2026-07-04 Added gerber and symbol libraries
    [retroslop-B_Cu.gbr, retroslop-B_Mask.gbr, retroslop-B_Paste.gbr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]
2026-07-05 Some house keeping
    [retroslop.kicad_sch, rtc.kicad_sch]
2026-07-06 fixed things
    [device_decoder.kicad_sch, dma.kicad_sch, flag_registers.kicad_sch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]
2026-07-07 Upgraded speaker, esd protection, added dip sockets, adjusted routing
    [device_decoder.kicad_sch, dma.kicad_sch, flag_registers.kicad_sch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]
2026-07-08 adjustments to routing
    [pinout.kicad_sch]
2026-07-08 final commit before spinning
    [device_decoder.kicad_sch, dma.kicad_sch, flag_registers.kicad_sch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]
2026-07-09 final final review
    [isa_bus.kicad_sch, memory.kicad_sch, processor_and_control.kicad_sch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]
2026-07-09 silkscreen adjustments
2026-07-09 modified schematic a little
    [wait_state_generator.kicad_sch]
2026-07-10 minor adjustments
    [retroslop-B_Cu.gbl, retroslop-B_Mask.gbs, retroslop-B_Paste.gbp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]
2026-07-10 another minor adjustments
    [retroslop-B_Cu.gbl, retroslop-B_Mask.gbs, retroslop-B_Paste.gbp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]
2026-07-25 seperated kicad and code
    [device_decoder.kicad_sch, dma.kicad_sch, flag_registers.kicad_sch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]
